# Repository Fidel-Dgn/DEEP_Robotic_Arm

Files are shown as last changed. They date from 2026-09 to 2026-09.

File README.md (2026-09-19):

# DEEP_Robotic_Arm
Ce dépôt contient le développement complet d’un bras robotique autonome basé sur un microcontrôleur STM32G431 et la DEEP Purple Complete Board. Le système est conçu pour détecter, saisir, trier et déplacer des objets grâce à une combinaison de capteurs, de servomoteurs et d’algorithmes embarqués.

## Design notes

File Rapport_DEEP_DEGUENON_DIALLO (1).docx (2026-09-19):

PROJET DEEP

Digital Embedded Electronics Project

Livraison finale

Bras robotique de tri automatique par couleur

Système mécatronique de détection et de tri RGB sur carte Nucleo STM32G431KB

Information | Détail
Nom du projet | Bras robotique de tri automatique par couleur
Étudiants | DEGUENON Fidel — DIALLO Seydou Idrissa
Encadrant | BOUVIER Thierry
Établissement | ESEO — Angers
Cible | Carte Nucleo STM32G431KB (DEEP Purple Complete Board)

# Sommaire

Sous Word : clic droit sur le sommaire → « Mettre à jour les champs » (ou sélectionnez tout puis F9) pour afficher les titres et les numéros de page avant l’export en PDF.

# Introduction

Ce projet a pour objectif la conception et la réalisation d’un système mécatronique autonome capable d’identifier la couleur d’un objet (rouge, vert ou bleu) et d’assurer son tri automatique. Le système repose sur un bras robotique articulé, actionné par cinq servomoteurs, qui manipule et déplace les objets vers des zones de tri dédiées.

L’identification de la couleur est effectuée à l’aide d’un capteur APDS-9960, tandis que l’ensemble du processus est piloté par un microcontrôleur STM32G431KB assurant la coordination entre la détection, la prise et le dépôt de l’objet. Une interface homme-machine, implémentée sur un écran TFT ILI9341, assure le suivi en temps réel du fonctionnement (état courant, distance de l’objet, composantes RGB mesurées et couleur détectée).

Ce rapport présente successivement le cahier des charges, le manuel d’utilisation, l’affectation des ports, l’architecture logicielle et la machine à états, les tests réalisés, le suivi du projet ainsi que l’analyse critique du travail. Les compléments retenus sont détaillés en annexe.

# 1. Compléments choisis

Afin de valoriser le travail réalisé et de couvrir les six points de compléments associés à la note de projet, l’équipe a retenu les compléments suivants. Le complément B (design de PCB) est obligatoire ; les autres ont été choisis pour leur pertinence vis-à-vis d’un système mécatronique embarqué.

Code | Complément retenu | Points
B | Routage de PCB avec Nucleo (carte d’interface / shield) | 3
E | Mesure de consommation et d’énergie selon scénarios | 2
G | Gestion de version du code source (Git) | 1
I | Impact environnemental (analyse du cycle de vie) | 3
T | Jeu de tests pour valider une fonctionnalité | 1
| Total de points ciblés (6 retenus sur la note) | 10

À adapter selon le travail réellement finalisé avant la remise : ne conservez que les compléments dont l’annexe correspondante est complétée. Les barèmes indiqués sont les valeurs maximales de la trame.

Brève introduction aux compléments. Le complément B décrit la conception d’une carte d’interface fiabilisant la connectique des servomoteurs et la séparation des alimentations. Le complément E analyse la consommation du système en régimes statique et dynamique. Le complément G assure la traçabilité du code via un dépôt Git distant. Le complément I propose un inventaire de cycle de vie et des pistes d’écoconception. Enfin, le complément T décrit un jeu de tests de validation des butées des servomoteurs.

# 2. Remise du matériel et réutilisation des composants

La récupération des matériels prêtés est essentielle au maintien de l’activité pratique et à la réutilisation des cibles fournies par STMicroelectronics. L’équipe coche ci-dessous la situation applicable.

Élément | État / Engagement
Numéro de la carte Nucleo | ______
Restitution des périphériques, de la carte Nucleo, du câble USB et de l’ensemble du matériel prêté | ☐ Déjà rendu
| ☐ Sera rendu sous 10 jours
| ☐ Remise lors d’une JPO / forum — Date : __/__/20__

Cochez la case applicable (sous Word : cliquez devant la case et tapez « x », ou utilisez la police Wingdings).

# 3. Cahier des charges

## 3.1 Contexte et expression du besoin

Dans un contexte industriel de logistique ou de contrôle qualité, le tri de petits composants selon un critère visuel simple (la couleur) est une opération répétitive qui se prête naturellement à l’automatisation. Le besoin exprimé est donc le suivant : disposer d’un démonstrateur autonome capable de détecter la couleur d’un objet présenté et de le déplacer vers la zone correspondante, sans intervention humaine.

- Objectif : automatiser le tri de petits objets en se basant sur leur couleur.
- Fonction principale : identifier puis déplacer les objets vers trois zones distinctes (Rouge, Vert, Bleu).

## 3.2 Description fonctionnelle (point de vue utilisateur)

Le système repose sur une architecture embarquée pilotée par la carte STM32G431KB. Le programme principal est structuré autour d’une machine à états finis qui gère séquentiellement les phases de fonctionnement. Les principaux éléments matériels sont :

- un capteur de couleur et de proximité APDS-9960 (bus I2C) ;
- un écran TFT ILI9341 (bus SPI) pour l’interface utilisateur ;
- un bras robotique articulé commandé par cinq servomoteurs (signaux PWM) ;
- le microcontrôleur STM32G431KB comme unité de traitement.

L’ensemble fonctionne en boucle infinie, assurant un traitement continu des données et des actions. Le cycle fonctionnel se résume ainsi :

Détection de présence → Analyse de la couleur → Décision → Mouvement du bras → Retour à l’attente

## 3.3 Limites et contraintes

Contraintes techniques. La carte Nucleo STM32G431KB impose des ressources limitées (broches, timers, mémoire). Les servomoteurs nécessitent une alimentation de puissance séparée afin d’éviter les perturbations électriques sur la partie logique. La gestion simultanée des périphériques (I2C, SPI, et cinq voies PWM réparties sur trois timers) constitue une contrainte forte de mise en œuvre et d’affectation des broches.

Limites fonctionnelles. Le tri est limité à trois couleurs (rouge, vert, bleu), avec une détection fondée sur une comparaison directe des composantes RGB. La précision du bras dépend des servomoteurs (commande en boucle ouverte) : l’absence de retour de position peut entraîner des imprécisions de placement.

# 4. Manuel d’utilisation

Ce manuel décrit la mise en œuvre du système du point de vue de l’utilisateur final. Aucune connaissance des outils de développement n’est nécessaire.

## 4.1 Alimentation

Le système requiert deux alimentations distinctes, à respecter impérativement :

- Alimentation de puissance : 5 V continu, capable de fournir de 1 A à 2,5 A, dédiée aux cinq servomoteurs du bras.
- Alimentation logique : 12 V continu en entrée, régulée en interne en 5 V (régulateur LM7805) puis en 3,3 V (régulateur LF33CV) pour la carte et les périphériques.

Les deux masses (GND puissance et GND logique) doivent être reliées. Ne pas alimenter les servomoteurs depuis le régulateur logique sous peine de chute de tension et de redémarrage du microcontrôleur.

## 4.2 Mise en route et utilisation

1. Mettre sous tension les deux alimentations ; la LED verte de la carte s’allume pour indiquer que le système est actif.
2. L’écran affiche le bandeau « ROBOTIC ARM PROJECT – ESEO » puis l’état courant en grand caractères. Le bras se place automatiquement en position de repos (état INIT).
3. Lorsque l’écran indique « ATTENTE OBJET », présenter un objet coloré sous le capteur. Une jauge de distance se remplit à l’approche de l’objet.
4. Une fois l’objet suffisamment proche, le système passe en « ANALYSE » : il affiche les valeurs Rouge, Vert et Bleu mesurées, ainsi qu’un carré de prévisualisation à la couleur détectée et le résultat (ROUGE, VERT ou BLEU).
5. Le bras saisit alors l’objet, pivote vers la zone correspondant à sa couleur, le dépose, puis revient en position d’attente pour l’objet suivant.

L’affichage permet à tout moment de savoir dans quel état se trouve la machine et quelle décision a été prise, sans recourir à un outil externe.

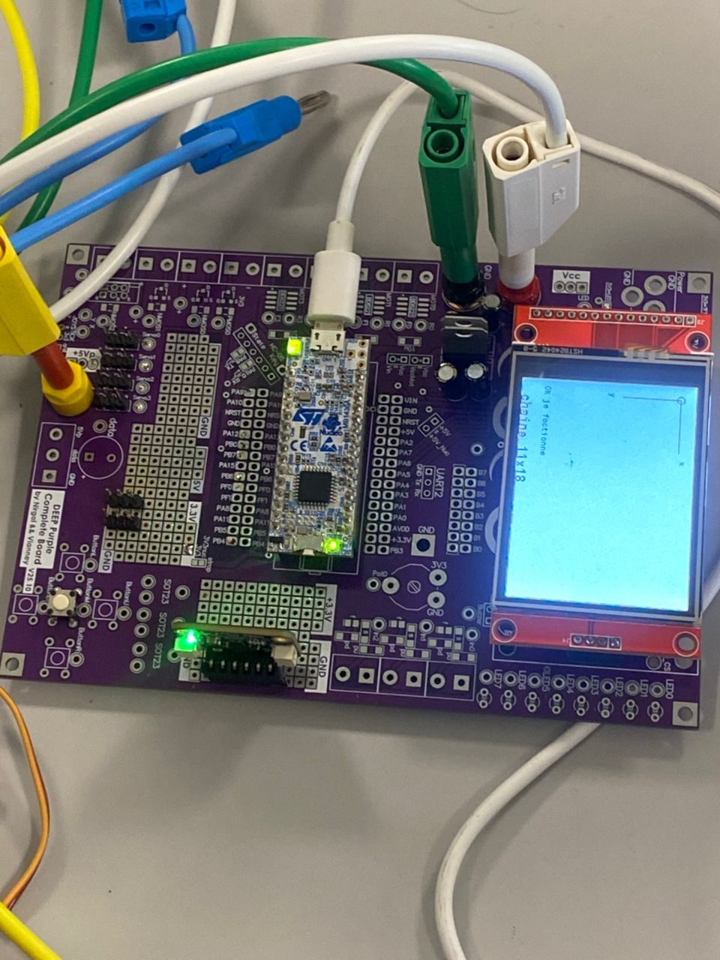
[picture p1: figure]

Figure 1 — Banc de test : carte DEEP Purple, Nucleo STM32G431KB et écran TFT ILI9341 actif.

# 5. Affectation des ports du microcontrôleur

Le tableau ci-dessous récapitule l’affectation des broches dans l’application. Les cinq voies de commande des servomoteurs (PWM) sont issues du code source (fichiers servo.c et main.c) et réparties sur trois timers.

Pin | Fonction dans le projet
PA9 | UART1 TX (réserve, non utilisé)
PA10 | PWM TIMER1_CH3 → Servo Coude
NRST | Reset microcontrôleur
GND | Masse
PA12 | SPI1 – contrôle écran TFT (CS / DC)
PB0 | PWM TIMER3_CH3 → Servo Épaule
PB7 | I2C1 SDA – capteur APDS-9960
PA15 | SPI1 / contrôle écran TFT
PB6 | I2C1 SCL – capteur APDS-9960
PF0 | Oscillateur (non utilisé)
PF1 | Oscillateur (non utilisé)
PA8 | Libre
PA11 | USB (non utilisé)
PB5 | Libre
PB4 | PWM TIMER3_CH1 → Servo Base
VIN | Alimentation carte (5 V)
GND | Masse
NRST | Reset
5V | Alimentation périphériques
PA2 | UART2 TX → PC (printf, 115200 bauds)
PA7 | SPI1 MOSI – écran TFT
PA6 | SPI1 MISO – écran TFT
PA5 | SPI1 SCK – écran TFT
PA4 | SPI1 CS – écran TFT
PA3 | UART2 RX ← PC
PA1 | PWM TIMER2_CH2 → Servo Pince
PA0 | PWM TIMER2_CH1 → Servo Poignet
AVDD | Alimentation analogique
3V3 | Alimentation logique
PB3 | SPI1 / contrôle écran TFT
PB8 | LED verte (indication système actif)

Aucun GPIO Expander n’a été utilisé : les 5 voies PWM, le bus SPI, le bus I2C et l’UART tiennent directement sur les broches de la Nucleo G431KB.

# 6. Câblage du PCB

Les périphériques sont intégrés sur la DEEP Purple Complete Board, qui accueille la carte Nucleo et les barrettes de connexion soudées pour les servomoteurs, le capteur et l’écran. La photographie ci-dessous présente une vue d’ensemble de la maquette ; le routage du PCB d’interface dédié est détaillé en Annexe B.

Figure 2 — Vue d’ensemble de la maquette câblée (recto).

[À INSÉRER : photo recto-verso du PCB d’interface câblé / soudé, une fois disponible]

# 7. Description d’un algorithme du programme

Le comportement global du système est décrit par une machine à états finis (FSM) implémentée dans la boucle principale du fichier main.c. Quatre états structurent le fonctionnement : INIT, WAIT_APDS, DECISION et TRIE. Le diagramme suivant présente les états et les conditions de transition.

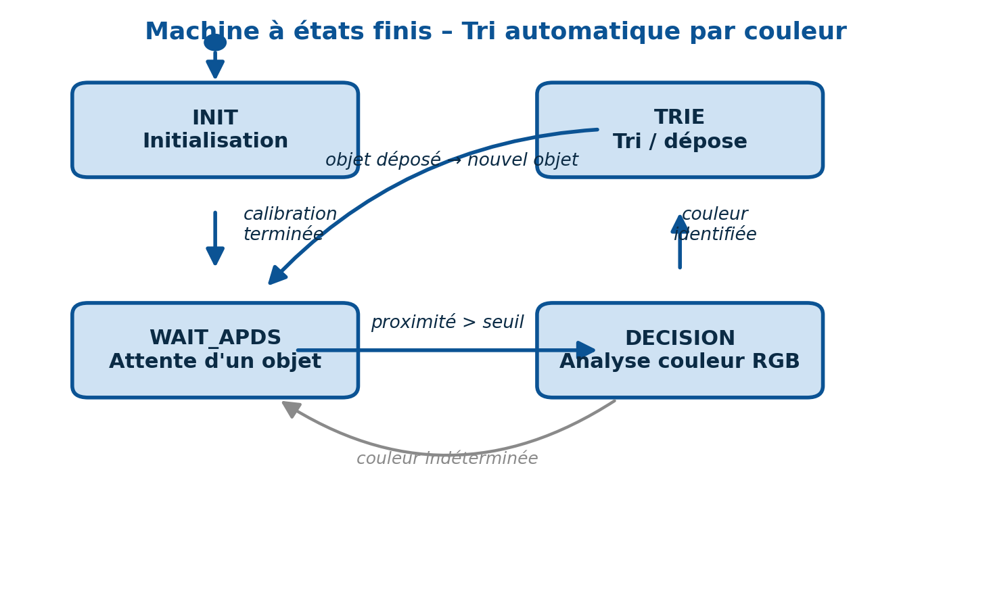
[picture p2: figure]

Figure 3 — Machine à états finis du système de tri.

## 7.1 Description des états

- INIT (Initialisation) — le système initialise et calibre le capteur APDS-9960, place le bras en position de repos (SERVO_set_position_INIT) puis active le capteur. La transition vers WAIT_APDS est inconditionnelle après une temporisation.
- WAIT_APDS (Attente d’un objet) — lecture continue de la proximité ; une jauge est affichée à l’écran. Lorsque la valeur dépasse le seuil PROXIMITY_THRESHOL, le système passe en DECISION.
- DECISION (Analyse) — lecture des composantes Rouge, Vert et Bleu. La couleur dominante est déterminée par comparaison directe ; la position de base cible est mémorisée (target_base_angle) et le système passe en TRIE. Si aucune couleur ne domine, retour à WAIT_APDS.
- TRIE (Tri / dépose) — le bras saisit l’objet (SERVO_pick_object), pivote vers la zone correspondante et dépose l’objet (SERVO_drop_at), puis revient en position initiale avant de repasser en WAIT_APDS.

## 7.2 Table de transition

État courant | Condition de transition | État suivant
INIT | Calibration terminée (temporisation) | WAIT_APDS
WAIT_APDS | proximité > PROXIMITY_THRESHOL | DECISION
DECISION | Couleur dominante identifiée (R, G ou B) | TRIE
DECISION | Couleur indéterminée | WAIT_APDS
TRIE | Objet déposé et bras revenu au repos | WAIT_APDS

## 7.3 Pseudo-code de la boucle principale

tant que (vrai) :
si (etat != etat_precedent) : rafraichir l'ecran (bandeau + nom d'etat)
selon etat :
INIT : init capteur ; bras au repos ; etat <- WAIT_APDS
WAIT_APDS : lire proximite ; afficher jauge
si proximite > SEUIL : etat <- DECISION
DECISION : lire R, G, B ; afficher valeurs
si R max : cible <- ROUGE ; etat <- TRIE
sinon si G max : cible <- VERT ; etat <- TRIE
sinon si B max : cible <- BLEU ; etat <- TRIE
sinon : etat <- WAIT_APDS
TRIE : SERVO_pick_object() ; SERVO_drop_at(cible)
SERVO_set_position_INIT() ; etat <- WAIT_APDS

# 8. Structure du programme

Le projet s’appuie sur le squelette BSP fourni pour la carte Nucleo STM32G431KB. Le code spécifiquement développé par l’équipe se trouve dans le dossier app/. Les modules matériels (écran, capteur, timers, bus de communication) sont pilotés via les drivers BSP réutilisés. Les fichiers produits par l’équipe sont décrits ci-dessous.

## 8.1 Fichier « config.h »

Fichier central de configuration : il active les modules logiciels utilisés par le projet. Sont activés ici l’écran ILI9341 (USE_ILI9341), le capteur APDS-9960 (USE_APDS9960), les timers (USE_BSP_TIMER) ainsi que les bus I2C et SPI (activés automatiquement par dépendance). Les UART1 et UART2 sont configurés respectivement sur PA9/PA10 et PA2/PA3, et la LED verte sur PB8.

## 8.2 Fichier « main.c »

Point d’entrée de l’application. Il réalise l’initialisation matérielle (HAL, écran, GPIO, UART à 115200 bauds, capteur, servomoteurs) puis exécute la machine à états dans la boucle infinie. Il gère également l’affichage de l’interface (bandeau, état courant, jauge de proximité, valeurs RGB et résultat de tri).

Fonction | Développeur | Description
main | F. Deguenon | Initialisation des périphériques et exécution de la machine à états (INIT, WAIT_APDS, DECISION, TRIE).
isButtonPressed | F. Deguenon | Teste si les coordonnées tactiles tombent dans la zone d’un bouton de l’écran.
write_LED | S. Diallo | Pilote l’état de la LED verte (témoin système).
char_received | S. Diallo | Indique si un caractère a été reçu sur l’UART et vide le buffer.
heartbeat | S. Diallo | Fait clignoter la LED tant qu’aucun caractère n’est reçu (témoin de vie).
TestCharReceiveUart | F. Deguenon | Émet bit à bit un caractère sur PA5 pour visualisation à l’oscilloscope (debug).
Test_Ecran | S. Diallo | Séquence de test de l’écran (couleurs, formes, texte).
example_rgb_read | F. Deguenon | Lecture et affichage des composantes ambiante/RGB via printf (debug).

## 8.3 Fichiers « servo.c » / « servo.h »

Module de pilotage des cinq servomoteurs du bras. Chaque servo est commandé par un signal PWM de période 20 ms (50 Hz) généré par les timers TIMER1, TIMER2 et TIMER3. La position est exprimée via le rapport cyclique réglé par BSP_TIMER_set_duty. Le module fournit les séquences de mouvement de préhension et de dépose.

Fonction | Développeur | Description
SERVO_init | Équipe | Lance les 3 timers à 20 ms et active les 5 voies PWM (Base PB4, Épaule PB0, Coude PA10, Poignet PA0, Pince PA1).
SERVO_set_position_INIT | Équipe | Place le bras en position de repos (valeurs de duty de référence).
SERVO_pick_object | F. Deguenon | Séquence de préhension : ouverture pince, descente, fermeture sur l’objet, remontée.
SERVO_drop_at | F. Deguenon | Pivote la base vers la zone de la couleur, ouvre la pince pour déposer puis relève le bras.
SERVO_process_test | S. Diallo | Routine de test d’un servo (balayage de positions, incrément sur bouton).
SERVO_set_position / SERVO_get_position | Équipe | Conversion position (0–100 %) → rapport cyclique (version de référence, conservée en commentaire).

## 8.4 Drivers BSP réutilisés

Outre le code applicatif, le projet s’appuie sur les drivers BSP fournis : stm32g4_ili9341 (écran TFT, SPI), APDS9960/stm32g4_apds9960 (capteur couleur/proximité, I2C), stm32g4_timer (génération PWM), stm32g4_i2c et stm32g4_spi (bus), stm32g4_uart (liaison série), stm32g4_gpio et stm32g4_systick (GPIO et base de temps).

# 9. Tests

Cette section présente les tests réalisés à chaque étape de la mise au point, avec le mode opératoire et le résultat observé. Ce rapport de test permet de situer l’état d’avancement de la réalisation.

Intitulé du test | Mode opératoire / observation attendue | Observation et conclusion
Alimentation 5 V de puissance | Mesure de la ligne 5 V dédiée aux servomoteurs ; doit rester stable en charge. | OK – tension stable mesurée à l’oscilloscope (voir Fig. 4).
Sortie régulateur LM7805 (5 V) | Mesure au voltmètre / oscilloscope de la sortie du LM7805. | OK – 4,96 V mesurés (voir Fig. 5).
Sortie régulateur LF33CV (3,3 V) | Mesure de la sortie 3,3 V alimentant la logique. | OK – 3,28 V mesurés (voir Fig. 6).
Liaison UART Tx → PC | Envoi de caractères depuis la STM32 (« Hi ») visualisés à l’oscilloscope et sur le terminal Docklite. | OK – trame série correcte observée (voir Fig. 7).
Écran TFT ILI9341 | Initialisation et affichage d’une chaîne de caractères. | OK – affichage correct (voir Fig. 1).
Servomoteurs (PWM) | Visualisation des impulsions PWM (20 ms) générées par les timers à l’oscilloscope. | OK – largeurs d’impulsion variables selon la commande (voir Fig. 8).
Bus I2C – APDS-9960 | Observation des lignes SDA et SCL lors des échanges avec le capteur. | OK – trames I2C présentes (voir Fig. 9 et 10).
Détection de couleur RGB | Présenter un objet rouge/vert/bleu et vérifier le résultat affiché. | Partiel – détection fonctionnelle mais sensible à l’éclairage ambiant et au gain du capteur.
Séquence complète de tri | Cycle détection → préhension → dépose → retour. | En cours – cinématique du bras en finalisation.

## 9.1 Mesures d’alimentation

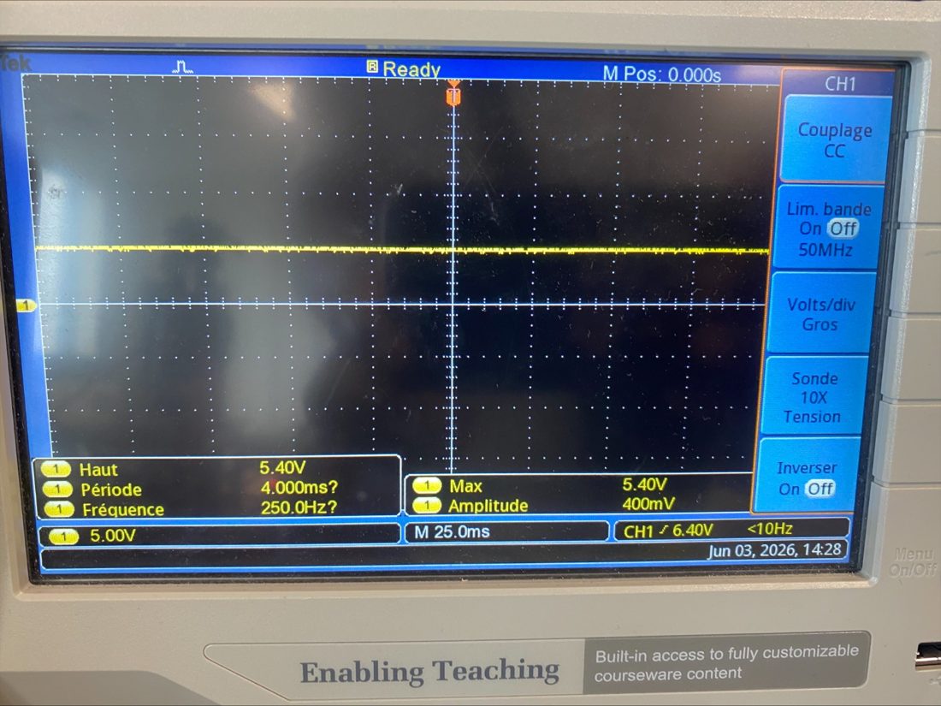
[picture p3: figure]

Figure 4 — Ligne d’alimentation 5 V de puissance (servomoteurs).

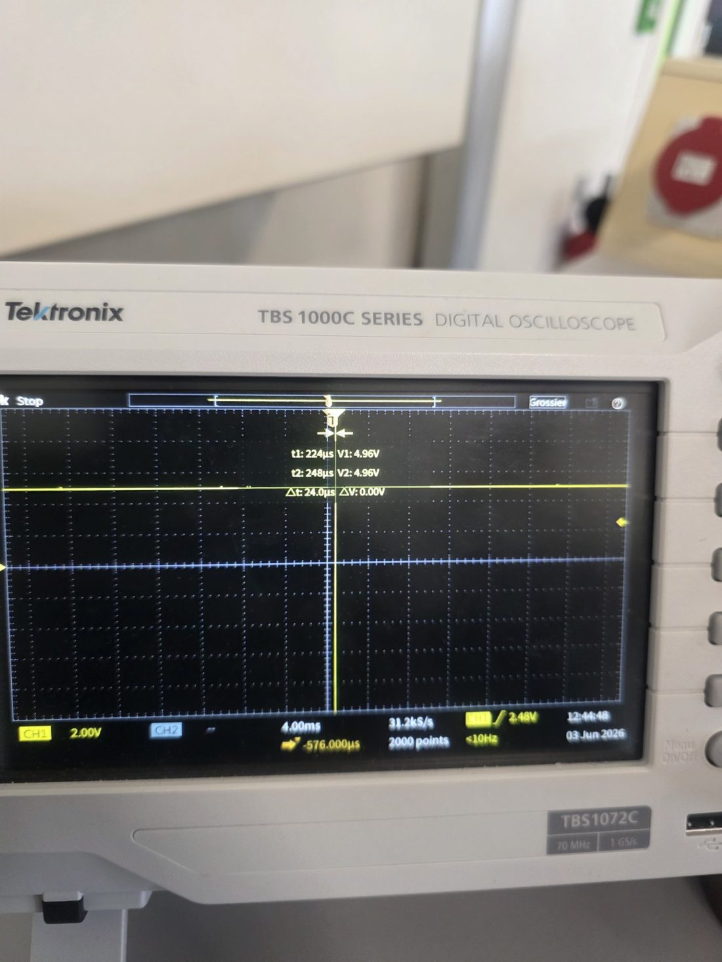
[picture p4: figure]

Figure 5 — Sortie du régulateur LM7805 : 4,96 V.

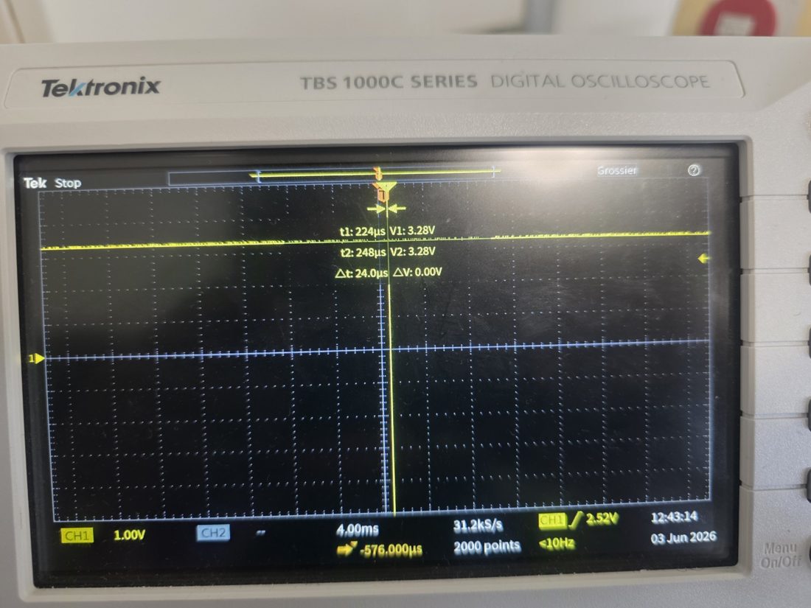
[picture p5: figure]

Figure 6 — Sortie du régulateur LF33CV : 3,28 V.

## 9.2 Communications et actionneurs

Le test de l’UART vérifie l’intégrité de la liaison bidirectionnelle entre la STM32 et le PC. La configuration utilise l’UART2 (PA2). Les premiers caractères émis (« Hi ») ont été visualisés à l’oscilloscope.

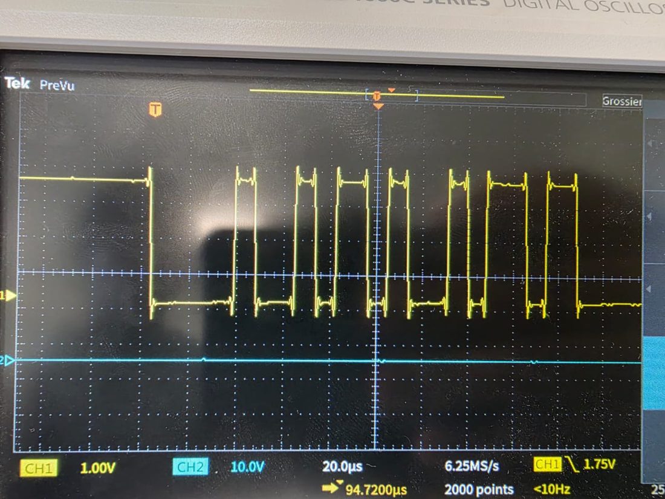
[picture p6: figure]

Figure 7 — Trame série UART (émission des caractères « Hi »).

Le test des servomoteurs valide la génération des impulsions PWM par les timers. Les largeurs d’impulsion varient correctement selon la commande, confirmant la capacité du microcontrôleur à piloter les servos.

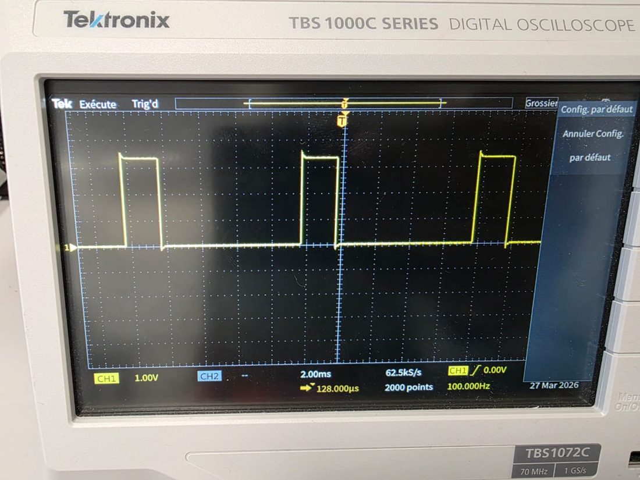
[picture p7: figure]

Figure 8 — Signaux PWM de commande des servomoteurs (période 20 ms).

Le test du capteur APDS-9960 vérifie la communication sur le bus I2C1 : ligne de données SDA et ligne d’horloge SCL. Les trames I2C sont bien présentes lors des échanges, validant l’initialisation du bus et le dialogue avec le capteur.

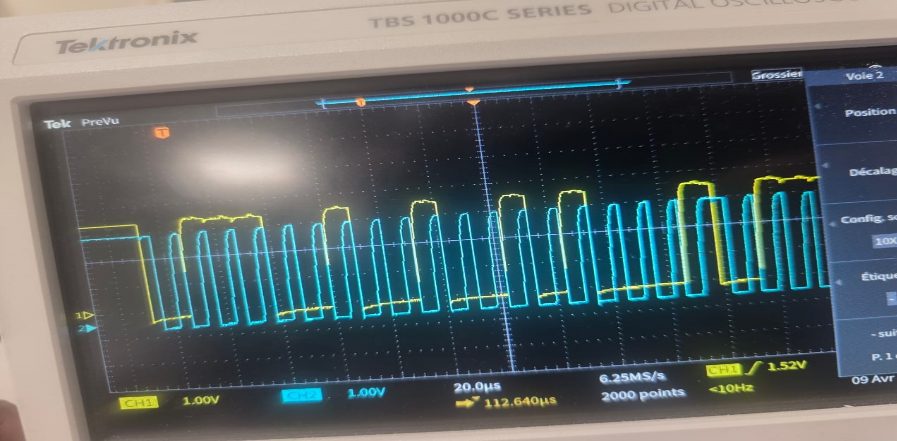
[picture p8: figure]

Figure 9 — Échanges I2C (SDA en jaune, SCL en bleu).

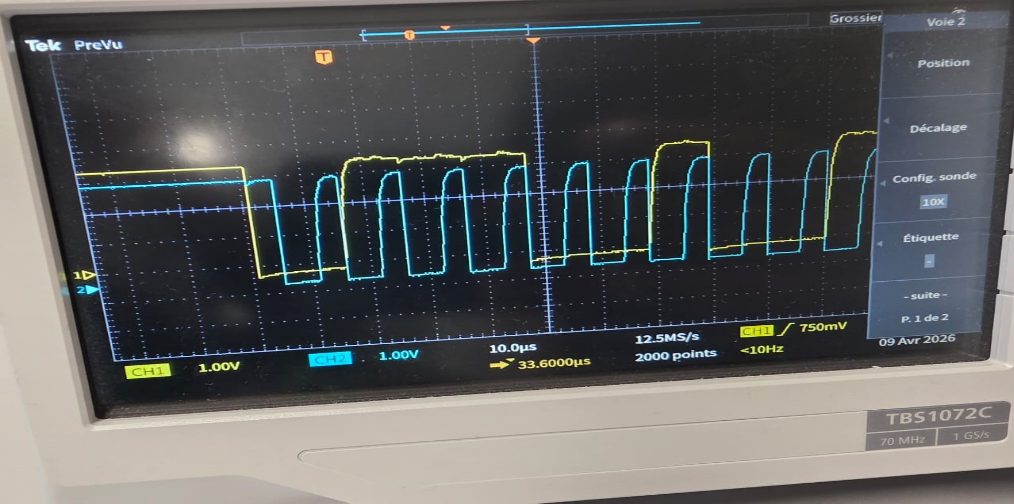
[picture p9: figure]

Figure 10 — Détail des trames I2C (données et horloge).

# 10. Cahier de suivi

Ce cahier retrace l’évolution du projet séance par séance : tâches réalisées, réalisateurs, difficultés rencontrées et actions à mener ensuite.

Date | Tâches, réalisateurs, difficultés rencontrées | À faire la prochaine fois
06/03 | Choix du sujet et définition du projet de bras robotique de tri. Répartition des tâches (F. Deguenon / S. Diallo). | Conception du système et architecture globale.
11/03 | Soudure des composants et barrettes sur la DEEP Purple Complete Board. Difficulté : organisation du câblage. (F. / S.) | Finalisation de l’intégration des périphériques.
13/03 | Gestion de l’alimentation : séparation puissance / logique pour éviter les parasites. Difficulté : stabilité électrique. | Tests UART et servomoteurs.
18/03 | Tests de communication UART entre la carte et le terminal PC. (F. Deguenon) | Intégration de l’écran TFT.
25/03 | Tests de l’écran ILI9341 et affichage des données. Début des tests PWM. Difficulté : réglage des fréquences PWM (tremblements). | Intégration des servomoteurs au bras.
27/03 | Tests des servomoteurs (timers PWM) et mouvements de base. Difficulté : calibration des angles et synchronisation. | Implémentation du capteur APDS-9960 en I2C.
01/04 | Implémentation et tests du bus I2C pour l’APDS-9960. Difficulté : instabilité I2C et erreurs de communication. | Stabilisation I2C et amélioration de la détection.
08/04 | Mise en place de la machine à états (INIT, WAIT_APDS, DECISION, TRIE). (F. Deguenon) | Finalisation de la logique de tri et intégration.
10/04 | Conception du PCB et organisation des signaux. Difficulté : conflits de GPIO entre modules. | Finalisation du routage PCB.
22/04 | Mise en ligne du projet sur Git (gestion de version et sauvegarde). (F. / S.) | Tests globaux et optimisation.
29/04 | Tests globaux et intégration complète. Début de la cinématique du bras. Difficultés : cinématique complexe, conflits GPIO. | Finalisation de la cinématique et optimisation.

# 11. État d’avancement et analyse du projet

## 11.1 État d’avancement

Le projet est bien avancé sur la partie matérielle et partiellement fonctionnel sur la partie logicielle.

Réalisations matérielles :

- intégration de la DEEP Purple Complete Board et des périphériques ;
- soudure des composants et mise en place des barrettes de connexion ;
- gestion de l’alimentation et vérification de la stabilité des tensions ;
- organisation du câblage entre les modules.

Réalisations logicielles :

- communication UART carte ↔ PC opérationnelle ;
- affichage TFT fonctionnel (interface et debug) ;
- commande des servomoteurs par PWM validée ;
- communication I2C avec le capteur APDS-9960 établie ;
- machine à états implémentée et enchaînement des états validé.

Points restant à finaliser :

- fiabilisation de la détection de couleur (gain capteur, conditions d’éclairage) ;
- calibration fine de la cinématique du bras (angles de préhension et de dépose) ;
- validation du cycle de tri complet en conditions réelles.

## 11.2 Analyse du travail réalisé

Analyse du matériel. Si la partie matérielle devait être refaite, plusieurs améliorations seraient envisagées : meilleure planification du câblage dès le départ, connecteurs plus robustes et standardisés pour éviter les faux contacts, ajout d’une plaque de distribution d’alimentation, et séparation plus nette des circuits de puissance et de logique pour réduire les perturbations.

Analyse du logiciel. Le code fonctionne pour les fonctions de base mais gagnerait à être davantage modularisé (séparation nette moteurs / communication / capteurs) et à remplacer les temporisations bloquantes (HAL_Delay) par une gestion non bloquante afin de fluidifier l’IHM pendant les mouvements.

Débogage. L’oscilloscope s’est révélé l’outil le plus utile (UART, PWM, I2C). Avec le recul, l’analyseur logique aurait pu être employé plus tôt pour déchiffrer les trames I2C et accélérer la stabilisation du capteur.

Difficultés principales. Instabilité de l’alimentation lors de l’activation simultanée de plusieurs servomoteurs ; conflits d’affectation de GPIO entre PWM, SPI et I2C ; complexité du câblage rendant certains diagnostics longs ; nombreux essais itératifs pour stabiliser les communications.

# 12. Conclusion

Ce projet de bras robotique illustre une démarche complète d’ingénierie, de la conception matérielle à l’implémentation logicielle jusqu’à la validation expérimentale. L’architecture fondée sur une machine à états finis a permis un fonctionnement structuré et lisible du système, et chaque brique (alimentation, UART, écran, PWM, I2C) a été validée individuellement à l’oscilloscope.

Au-delà des résultats, le projet met en évidence les défis concrets des systèmes embarqués : gestion de l’énergie, séparation des alimentations, affectation des broches sous contrainte, précision des actionneurs en boucle ouverte. La principale difficulté surmontée a été la stabilisation conjointe des alimentations et des bus de communication face à la charge variable des servomoteurs.

Le système constitue une base solide pour des développements futurs : fiabilisation de la détection de couleur, passage à une commande non bloquante et calibration fine de la cinématique. Il reflète une approche rigoureuse de la conception d’un système robotique complet.

# Annexe B — Design de PCB (complément obligatoire)

Cette annexe présente la carte d’interface conçue pour fiabiliser la connectique des servomoteurs, des bus et de l’alimentation autour de la Nucleo STM32G431KB.

## B.1 Auto-validation avant fabrication

Critère de validation | Statut
Fichiers SchDoc, PcbDoc et PDF (schéma + couches + vue 3D) joints à l’archive zip | ☐
Chaque point de la « fiche validation PCB avant fabrication » consulté | ☐
Connecteurs accessibles | ☐
Plan de masse présent sur chaque couche de cuivre | ☐
Tous les GND reliés par des pistes | ☐
DRC (Design Rules Check) sans aucune erreur | ☐
Connecteur UART présent (Rx + Tx + GND) | ☐
Connecteur de programmation si microcontrôleur en CMS (SWDIO + SWDCLK + GND) | ☐
Noms des étudiants et site (Angers) visibles sur le TOP | ☐
Dimensions raisonnables, pistes ≥ 10 mils (20 si possible), clearance ≥ 20 mils si possible | ☐

## B.2 Auto-évaluation

Critère | Note / 100
Qualité du schéma | ____ / 100
Qualité du placement | ____ / 100
Qualité du routage | ____ / 100

## B.3 Schéma, routage et vue 3D

[À INSÉRER : extraits du schéma (capture) avec explication du rôle des composants/périphériques]

[À INSÉRER : vue 2D du routage, plans de masse masqués]

[À INSÉRER : vue 3D du PCB (Top, et Bottom si pertinent)]

Difficultés rencontrées : conflits d’affectation de GPIO entre PWM, SPI et I2C lors du placement, et acheminement des pistes d’alimentation de puissance séparées de la partie logique.

## B.4 Estimation du coût de production

[À INSÉRER : capture de l’estimation de coût (JLCPCB, Eurocircuits, …) à partir des fichiers Gerber]

# Annexe E — Mesure de consommation et d’énergie selon scénarios

L’alimentation est un enjeu critique du système, notamment du fait des cinq servomoteurs dont la consommation varie fortement selon qu’ils sont au repos ou en mouvement.

## E.1 Modes de fonctionnement

- Mode veille / attente : capteur actif, écran statique, servomoteurs maintenus en position (couple de maintien).
- Mode actif : analyse couleur et mouvement simultané de plusieurs servomoteurs (pic de courant).

## E.2 Mesures par mode

Mode / scénario | Courant mesuré | Observations
Repos (attente d’objet) | ____ mA | À compléter
Analyse (capteur + écran) | ____ mA | À compléter
Mouvement (préhension) | ____ mA (pic) | À compléter
Cycle de tri complet | ____ mAh | À compléter

Relevés à compléter avec la méthodologie de la notice « Complément E ». Penser à décrire un scénario type et à estimer l’énergie consommée (voire le dimensionnement d’une batterie).

## E.3 Pistes de réduction de la consommation

- Couper l’alimentation des servomoteurs hors mouvement (relais / MOSFET de puissance).
- Mettre le microcontrôleur en mode veille (Sleep/Stop) pendant l’attente, réveil sur interruption de proximité.
- Réduire la fréquence de rafraîchissement de l’écran et désactiver le capteur entre deux objets.

# Annexe G — Gestion de version du code source (Git)

Le code source du projet est géré sous Git et hébergé sur un dépôt distant, assurant la traçabilité des modifications et facilitant le travail collaboratif entre les deux membres de l’équipe.

Dépôt : https://github.com/Fidel-Dgn/stm32-projet-robotic-arm.git

[À INSÉRER : capture d’écran de l’historique des révisions (dates et auteurs des commits visibles)]

## Retour d’expérience

L’utilisation de Git a permis de sauvegarder régulièrement le travail et de revenir à une version stable après une modification problématique (notamment lors de la mise au point de l’I2C et des réglages PWM). Le suivi des commits étalés sur la durée du projet reflète la progression réelle du développement, depuis l’intégration des périphériques jusqu’à la machine à états.

# Annexe I — Impact environnemental

En s’appuyant sur le cours du semestre 5, cette annexe esquisse l’inventaire du cycle de vie (ICV) d’un équivalent industriel du bras robotique de tri, puis propose des pistes d’écoconception. Le périmètre retenu est volontairement simplifié pour cette étude.

## I.1 Inventaire du cycle de vie (ICV) — périmètre simplifié

Phase | Principaux flux / impacts
Extraction & matériaux | Cuivre (PCB, câblage), plastiques (servos, boîtier), silicium (microcontrôleur, capteur), métaux des connecteurs.
Fabrication | Gravure et métallisation du PCB (consommables chimiques, eau), assemblage et soudure (énergie, alliages).
Distribution | Transport des composants (souvent importés) et du produit fini.
Utilisation | Consommation électrique (servos, logique) sur la durée de vie ; source d’énergie déterminante.
Fin de vie | DEEE : tri, recyclage des métaux et du PCB, traitement des plastiques.

## I.2 Trois pistes d’écoconception

6. Sobriété énergétique : mise en veille du microcontrôleur et coupure des servomoteurs hors mouvement (cf. Annexe E) pour réduire l’impact de la phase d’utilisation, généralement dominante.
7. Durabilité et réparabilité : connecteurs standardisés et modules enfichables (capteur, écran, bras) pour faciliter le remplacement d’un seul composant défaillant plutôt que de l’ensemble.
8. Conception matière : PCB de dimensions optimisées (moins de cuivre et de substrat), boîtier en matériau recyclé/recyclable et limitation du nombre de références de composants.

# Annexe T — Jeu de tests de validation

Le projet dispose d’une fonctionnalité se prêtant à un jeu de tests : la validation des butées et des positions de référence des servomoteurs à la mise sous tension, afin de garantir que le bras ne force pas mécaniquement et atteint bien ses positions clés.

## T.1 Cas de test

N° | Cas testé / action | Résultat attendu
1 | Mise sous tension : appel de SERVO_set_position_INIT. | Chaque servo rejoint sa position de repos sans forcer.
2 | Commande de la base aux positions ROUGE / VERT / BLEU. | La base s’oriente vers les trois angles distincts attendus.
3 | Commande pince ouverte puis fermée. | La pince atteint les deux butées sans blocage.
4 | Position de duty hors plage (< min ou > max). | La valeur est écrêtée ; aucun mouvement dangereux.
5 | Séquence SERVO_pick_object puis SERVO_drop_at. | Préhension et dépose enchaînées, retour au repos.

La pertinence de ce jeu de tests réside dans la couverture des positions extrêmes (butées) et des transitions critiques, qui sont les situations les plus susceptibles d’endommager les servomoteurs ou la mécanique du bras.

DEGUENON Fidel – DIALLO Seydou Idrissa | Page

Projet DEEP — Bras robotique de tri par couleur

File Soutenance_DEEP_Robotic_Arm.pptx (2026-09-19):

## Projet d’électronique numérique

Bras robotique de tri automatique par couleur
Système mécatronique de détection et de tri RGB sur carte Nucleo STM32G431KB
Encadré par BOUVIER Thierry — ESEO Angers 2025

Projet réalisé par :
DEGUENON Fidel
DIALLO Seydou Idrissa

2023

ESEO :: Présentation du projet d’électronique numérique :: 2025

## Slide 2

Quelques conseils pour rédiger un support de présentation…
Sur chaque slide, posez vous les questions suivantes :
« quel message je veux faire passer » ?
Puis-je expliquer ce message avec une image :
Chronogramme, graphique, dessin, schéma, croquis, illustration, photo, …
Y-a-t-il beaucoup de texte ? / Puis-je résumer en quelques items ?
Est-ce lisible de loin / suffisamment contrasté ?
Est-ce que cette slide va servir mon discours ?

## Sommaire

- But du projet
- Fonctionnalités du dispositif
- Capteurs et actionneurs utilisés
- Développement matériel
  - Architecture
  - Problèmes rencontrés
- Développement logiciel
  - Architecture
  - Etats du système
  - Tests
  - Problèmes rencontrés
- Perspectives d’évolutions

## But du projet

- Contexte industriel :
  - Dans la logistique et le contrôle qualité, le tri visuel de composants est une tâche répétitive idéale pour l’automatisation.
- Objectif du projet :
  - Concevoir un système mécatronique autonome capable de détecter la couleur d’un objet (rouge, vert, bleu) et de le trier automatiquement.
- Fonction principale :
  - Identifier puis déplacer les objets vers 3 zones distinctes (Rouge, Vert, Bleu) sans intervention humaine.

## Spécifications

- Fonctionnalités principales
  - Détection de couleur (rouge, vert, bleu) via capteur APDS-9960
  - Tri automatique vers 3 zones dédiées — sans intervention humaine
  - Bras articulé 5 servomoteurs : base, épaule, coude, poignet, pince
  - Interface HMI sur écran TFT ILI9341 (état, distance, RGB, couleur détectée)
- Limites et contraintes
  - Tri limité à 3 couleurs — détection par comparaison directe des composantes RGB
  - Commande en boucle ouverte : précision dépendante des servomoteurs

## Composants utilisés

- Capteur APDS-9960 (I2C)
  - Détection de proximité et mesure des composantes Rouge, Vert, Bleu
- Microcontrôleur STM32G431KB (carte Nucleo)
  - Unité de traitement centrale — gestion I2C, SPI, PWM, UART
- 5 Servomoteurs (PWM 50 Hz)
  - Base (PB4), Épaule (PB0), Coude (PA10), Poignet (PA0), Pince (PA1)
- Écran TFT ILI9341 (SPI)
  - Affichage temps réel de l’état, proximité, valeurs RGB et résultat de tri
- Alimentation double
  - 5V puissance (servos) + 12V régulé en 5V (LM7805) puis 3,3V (LF33CV) pour logique

## Capteur de température DS18B20

- Principe de fonctionnement
  - Le capteur APDS-9960 mesure l’intensité lumineuse réfléchie dans les canaux Rouge, Vert, Bleu et Clear via des photodiodes internes.
- Protocole de communication : I2C (bus I2C1)
  - SDA → PB7 — SCL → PB6
  - Adresse I2C : 0x39 — driver BSP : stm32g4_apds9960
- Point technique : correction de saturation
  - Gain fixé à AGAIN_1X pour éviter la saturation des valeurs RGB en éclairage fort
- Limite
  - Détection sensible à l’éclairage ambiant — comparaison RGB directe sans correction colorimétrique

## Actionneur

- Principe de pilotage des servomoteurs
  - Signal PWM période 20 ms (50 Hz) — position codée par la largeur d’impulsion (1–2 ms)
  - Rapport cyclique réglé par BSP_TIMER_set_duty() via TIMER1, TIMER2, TIMER3
- Répartition des voies PWM
  - TIM3_CH1 (PB4) → Base — TIM3_CH3 (PB0) → Épaule
  - TIM1_CH3 (PA10) → Coude — TIM2_CH1 (PA0) → Poignet — TIM2_CH2 (PA1) → Pince
- Séquences de mouvement
  - SERVO_pick_object() : ouverture pince, descente, saisie, remontée
  - SERVO_drop_at() : pivot vers la zone couleur, dépose, retour repos

## Développement matériel

- DEEP Purple Complete Board
  - Carte d’interface accueillant la Nucleo + barrettes servos + connecteurs capteur/écran
- PCB conçu sous Altium Designer
  - Plan de masse sur chaque couche, DRC sans erreur, Gerber générés pour JLCPCB (5 exemplaires)
- Problèmes rencontrés
  - Conflits de GPIO entre PWM, SPI et I2C — résolu par affectation rigoureuse des broches
  - Instabilité de l’alimentation lors de l’activation simultanée de plusieurs servos — séparation puissance/logique
- Auto-évaluation PCB
  - Schéma 90/100 — Placement 95/100 — Routage 98/100

## Développement logiciel

- Découpage en modules
  - config.h — activation des modules (ILI9341, APDS9960, timers, I2C, SPI, UART)
  - main.c — init matérielle + machine à états + interface TFT
  - servo.c / servo.h — pilotage PWM des 5 servomoteurs + séquences pick/drop
  - Drivers BSP réutilisés : stm32g4_ili9341, stm32g4_apds9960, stm32g4_timer, stm32g4_i2c, stm32g4_spi, stm32g4_uart
- Rôle de chaque module
  - main.c : chef d’orchestre — servo.c : actionneur — APDS driver : détection — ILI9341 driver : affichage

## Développement logiciel - Etats du système

- Machine à 4 états (FSM)
  - INIT → calibration APDS-9960, position de repos → transition inconditionnelle vers WAIT_APDS
  - WAIT_APDS → lecture proximité en continu + jauge écran → si proximité > seuil : DECISION
  - DECISION → lecture RGB, couleur dominante → si identifiée : TRIE — sinon : retour WAIT_APDS
  - TRIE → SERVO_pick_object + pivot base + SERVO_drop_at + retour repos → WAIT_APDS
- Cycle fonctionnel complet
  - Détection de présence → Analyse couleur → Décision → Mouvement bras → Retour attente

## Développement logiciel - tests

- Approche itérative : validation périphérique par périphérique
  - Alimentation 5V puissance : OK — LM7805 : 4,96V — LF33CV : 3,28V
  - UART2 (PA2) : trame série correcte observée à l’oscilloscope (Docklite)
  - Servomoteurs PWM : largeurs d’impulsion variables selon commande — OK
  - Bus I2C APDS-9960 : trames SDA/SCL présentes — OK
  - Détection RGB : fonctionnelle — sensible à l’éclairage ambiant
  - Cycle complet de tri : implémenté, testé et validé (séance 05/06)

## Développement logiciel – problèmes rencontrés

- Problèmes rencontrés
  - Instabilité I2C lors des premiers tests — résolu par stabilisation du bus et du timing
  - Tremblements des servos au départ — réglage des fréquences PWM et calibration des angles
  - HAL_Delay() bloquant dans l’état DECISION — gel de l’IHM pendant les mouvements
  - Conflits GPIO entre PWM, SPI et I2C — résolution par affectation rigoureuse (voir tableau broches)
  - Cinématique complexe du bras — nombreux essais itératifs pour calibrer les positions

## Démonstration

- Démonstration live du système
  - 1. Mise sous tension : LED verte allumée, écran affiche « ROBOTIC ARM PROJECT – ESEO »
  - 2. État ATTENTE OBJET : jauge de proximité se remplit à l’approche
  - 3. État ANALYSE : affichage RGB + carré de prévisualisation couleur + résultat ROUGE/VERT/BLEU
  - 4. TRI : bras saisit l’objet, pivote, dépose dans la zone, revient en attente

## Perspectives

- Améliorations logicielles
  - Remplacer les HAL_Delay() bloquants par une gestion non bloquante (Systick/interruptions)
  - Meilleure modularisation du code : séparation nette moteurs / communication / capteurs
- Améliorations matérielles
  - Fiabilisation de la détection de couleur (correction colorimétrique, compensation luminosité)
  - Calibration fine de la cinématique — ajout d’un retour de position (encodeurs)
- Extension fonctionnelle
  - Tri de plus de 3 couleurs — vision artificielle (caméra) — boîtier CAO dédié

## Conclusion

- Un projet d’ingénierie complet
  - De la conception matérielle (PCB, câblage, alimentation) à l’implémentation logicielle (FSM, PWM, I2C, SPI) jusqu’à la validation expérimentale.
- Points clés retenus
  - Architecture FSM lisible — chaque brique validée individuellement à l’oscilloscope
  - Cycle de tri complet fonctionnel : détection → préhension → dépose
- Défis surmountés
  - Stabilisation des alimentations et des bus face à la charge variable des servomoteurs
  - Gestion des conflits GPIO — cinématique du bras calibrée itérativement

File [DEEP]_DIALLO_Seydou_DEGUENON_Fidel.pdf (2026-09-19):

## RAPPORT INTERMÉDIAIRE DU PROJET :

## DEEP

### DEGUENON Fidel

### DIALLO Seydou Idrissa

ENCADRANT :

BOUVIER Thierry

## Table des matières

## Introduction

Ce projet a pour objectif la conception et la réalisation d’un système mécatronique autonome capable d’identifier la couleur d’un objet (rouge, vert ou bleu) et d’assurer son
tri | automatique.
Le système repose sur l’utilisation d’un bras robotique articulé, actionné par cinq servomoteurs, permettant la manipulation et le déplacement des objets vers des zones de tri spécifiques.

L’identification de la couleur est effectuée à l’aide d’un capteur adapté, tandis que l’ensemble du processus est piloté par une unité de commande assurant la coordination entre la détection, la prise et le dépôt de l’objet.

Par ailleurs, une interface homme-machine, implémentée via un écran TFT, permet d’assurer un suivi en temps réel du fonctionnement du système, en affichant notamment les informations relatives à la détection et aux actions en cours.

## 1. Cahier des charges

### 1.1 Expression du besoin

Objectif : Automatiser le tri de petits composants en se basant sur la couleur.

Fonction principale : Identifier et déplacer des objets vers trois zones distinctes (Rouge, Vert, Bleu).

### 1.2 Description fonctionnelle (Point de vue utilisateur)

### 1.2.1 Organisation générale

Le système repose sur une architecture embarquée pilotée par une carte microcontrôleur STM32. Le programme principal est structuré autour d’une machine à états finis, permettant de gérer de manière séquentielle et cohérente les différentes phases du fonctionnement.

Les principaux éléments matériels utilisés sont :

− Un capteur de couleur et de proximité (APDS9960),
− Un écran TFT (ILI9341) pour l’interface utilisateur,
− Un bras robotique commandé par cinq servomoteurs,
− Une unité de traitement (microcontrôleur STM32).

L’ensemble du système fonctionne en boucle infinie, assurant un traitement continu des données et des actions.

### 1.2.2 Machine à états

Le comportement du système est défini par une machine à états composée de quatre états principaux :

− INIT (Initialisation)
− WAIT_APDS (Attente d’un objet)
− DECISION (Analyse de la couleur)
− TRIE (Exécution du tri)
Cette organisation permet de structurer clairement le déroulement du processus et d’assurer une transition logique entre les différentes étapes.

### 1.2.3 Description des états

Le fonctionnement du système repose sur une machine à états composée de quatre états principaux :

− INIT (Initialisation)
Le système configure et initialise les capteurs et les périphériques. Une phase de calibration est effectuée avant de passer en mode attente.
− WAIT_APDS (Attente d’objet)
Le système surveille la présence d’un objet à l’aide du capteur de proximité. Une jauge est affichée à l’écran pour guider le positionnement. Lorsque l’objet est détecté, le système passe à l’analyse.
− DECISION (Analyse)
Le système mesure les composantes rouge, verte et bleue de l’objet, puis détermine sa couleur dominante. En fonction du résultat, une position de tri est définie.
− TRIE (Trie)
Le bras robotique saisit l’objet, le déplace vers la zone correspondante à sa couleur, puis revient à sa position initiale. Le système repasse ensuite en attente.

Le fonctionnement global du système peut être résumé comme suit :

Détection de présence → Analyse de la couleur → Décision → Mouvement du bras → Retour à l’attente

### 1.3 Limites et contraintes

Contraintes | techniques | :
Le système repose sur la carte Nucleo STM32G431KB, ce qui impose des ressources limitées. Les servomoteurs nécessitent une alimentation séparée afin d’éviter les perturbations électriques. La gestion simultanée des interfaces (I2C, SPI, PWM) constitue également une contrainte de mise en œuvre.
Limites | | :
Le tri est limité à trois couleurs (rouge, vert, bleu) avec une détection basée sur une comparaison simple des valeurs RGB. La précision du bras dépend des servomoteurs (commande PWM) et l’absence de retour de position peut entraîner des imprécisions.

## 2. Composants utilisés

### 2.1 Tableau des périphériques

Cette section présente l’ensemble des composants matériels utilisés dans le projet, en précisant pour chacun leur rôle fonctionnel au sein du système, afin de mettre en évidence l’architecture globale du bras robotique et la contribution de chaque élément à son fonctionnement.

Nom ou Référence | Description / Rôle dans l'application
STM32G431KB | Cœur du système : gestion de la machine à états et génération des signaux PWM/SPI/I2C.
APDS-9960 | Capteur de proximité et de couleur. Déclenche la prise de décision via le bus I2C.
ILI9341 (LCD) | Écran de 2.4 pouces. Affiche l'interface graphique et les retours de debugging.
Servomoteurs MG996 | Actionneurs (5 au total) pour les articulations. Pilotage par rapport cyclique (PWM).

## 2.2 Affectation des ports du microcontrôleur

Cette section présente la répartition précise des broches du microcontrôleur en fonction des besoins du projet, en indiquant pour chaque pin la fonction associée (PWM, I2C, SPI, debug, etc.) afin d’assurer une organisation cohérente du hardware et de faciliter l’intégration des différents modules du bras robotique.

Pin | Fonction dans le projet
PA9 | UART2 TX (communication série vers PC)
PA10 | UART2 RX
NRST | Reset microcontrôleur
GND | Masse
PA12 | SPI / CS écran TFT (ILI9341)
PB0 | PWM Servo (axe bras)
PB7 | I2C / signal capteur APDS9960
PA15 | SPI / signal TFT (CS ou contrôle)
PB6 | I2C SCL (capteur APDS9960)
PF0 | Oscillateur / non utilisé

PF1 | Oscillateur / non utilisé
PA8 | PWM Servo (axe épaule)
PA11 | USB / communication interne
PB5 | PWM Servo (axe pince ou coude)
PB4 | GPIO libre / non utilisé
VIN | Alimentation carte
GND | Masse
NRST | Reset
5V | Alimentation périphériques
PA2 | UART2 TX (alternative selon config BSP)
PA7 | SPI (MOSI TFT)
PA6 | SPI (MISO TFT)
PA5 | SPI (SCK TFT)
PA4 | SPI / Chip Select TFT
PA3 | UART RX / GPIO
PA1 | PWM Servo
PA0 | PWM Servo
AVDD | Alimentation analogique
3V3 | Alimentation logique
PB3 | SPI / signal TFT
PB8 | LED verte (indication système ON)

## 3. Cahier de suivi

Cette section retrace l’évolution du projet au fil des séances, en précisant les tâches réalisées par chaque membre de l’équipe, les difficultés rencontrées et les actions prévues pour la suite, afin d’assurer un suivi rigoureux et une progression cohérente du développement du bras robotique.

Date | Tâches, réalisateurs, difficultés rencontrées | À faire la prochaine fois
06/03 | Choix du sujet et définition du projet de bras robotique de tri. Répartition des tâches entre Fidel DEGUENON et Seydou DIALLO. | Début de la conception du système et architecture globale
11/03 | Soudure de composants et barrettes sur la carte DEEP Purple Complete Board pour intégrer les périphériques. Difficulté : organisation du câblage et adaptation aux contraintes matérielles. (Fidel / Seydou) | Finalisation de l’intégration des périphériques
13/03 | Gestion de l’alimentation du projet avec séparation des alimentations moteurs et logique pour éviter les parasites. Difficulté : stabilité électrique du système lors des premiers tests. | Tests des communications UART et servomoteurs

18/03 | Tests de communication UART entre la carte et le terminal PC. (Fidel DEGUENON) | Intégration écran TFT
25/03 | Tests de l’écran TFT ILI9341 et affichage des données système. Début des tests PWM pour servomoteurs. Difficulté : réglage des fréquences PWM pour éviter les tremblements des servos. | Intégration des servomoteurs au bras
27/03 | Tests des servomoteurs (contrôle via timers PWM). Validation des mouvements de base du bras robotique. Difficulté : calibration des angles et synchronisation des mouvements. | Implémentation du capteur APDS9960 en I2C
01/04 | Implémentation et tests du bus I2C pour le capteur APDS9960 (couleur et proximité). Difficulté : instabilité du bus I2C et erreurs de communication avec le capteur. | Stabilisation I2C et amélioration détection
08/04 | Mise en place de la machine à états du système (INIT, WAIT_APDS, DECISION, TRIE). (Fidel DEGUENON) | Finalisation logique de tri et intégration globale
10/04 | Conception du PCB du projet et organisation des signaux des périphériques. Difficulté : choix et conflits de GPIO entre les différents modules. | Finalisation du routage PCB
22/04 | Mise en ligne du projet sur Git pour gestion de version et sauvegarde du code. (Fidel / Seydou DIALLO) | Tests globaux et optimisation du système
29/04 | Tests globaux du système et intégration complète des modules. Début de la cinématique du bras robotique (en cours). Difficultés : cinématique du bras complexe et encore en cours d’implémentation, gestion des conflits GPIO persistants. | Finalisation de la cinématique et optimisation des performances

## 4. État d'avancement et analyse

## 4.1. État d’avancement du projet

Le projet de bras robotique basé sur la Deep Purple Complete Board est actuellement bien avancé sur la partie matérielle et partiellement fonctionnel sur la partie logicielle. Réalisations matérielles :

− Mise en place de la carte Deep Purple Complete Board et intégration des différents périphériques.
− Soudure de certains composants et mise en place de barrettes de connexion pour accueillir les modules (servomoteurs, capteurs, etc.).
− Gestion de l’alimentation du système et vérification de la stabilité des tensions. − Organisation du câblage entre les différents modules afin d’assurer une meilleure lisibilité et maintenance.
− Installation des périphériques principaux sur la carte (UART, écran, modules de commande, etc.).

Réalisations logicielles :

− Tests de communication UART entre le microcontrôleur et les périphériques externes.
− Tests de communication avec un module Bluetooth pour le contrôle sans fil.
− Tests de commande des servomoteurs via des instructions simples.
− Premier déploiement de code permettant la réception et l’exécution de positions moteur.
Tests effectués :

− Test de l’alimentation des modules sans surcharge.

LM7805 (5V) : La mesure confirme que la tension est stable, permettant d'alimenter les servomoteurs et les périphériques logiques sans risque.

LF33CV (3.3V) : En tant que régulateur LDO (Low-Dropout), le LF33CV assure une tension précise pour le cœur du STM32. La valeur mesurée est conforme aux spécifications du fabricant.

− Vérification de la transmission UART.

Le test de l’UART (Universal Asynchronous Receiver-Transmitter) constitue l’étape initiale et essentielle de la validation de la chaîne de transmission. L’objectif est de vérifier l’intégrité de la liaison bidirectionnelle entre la carte STM32 et le PC, afin de s’assurer que les données transmises sont correctement reçues et interprétées par les deux systèmes.

Dans notre cas, la configuration de l’UART est réalisée sur la broche PA2, et c’est à ce niveau que nous avons vérifié le bon fonctionnement de la communication. Pour cela, nous avons visualisé à l’oscilloscope les premiers caractères envoyés (Hi) depuis la carte STM32 vers le PC, via le logiciel Docklite.

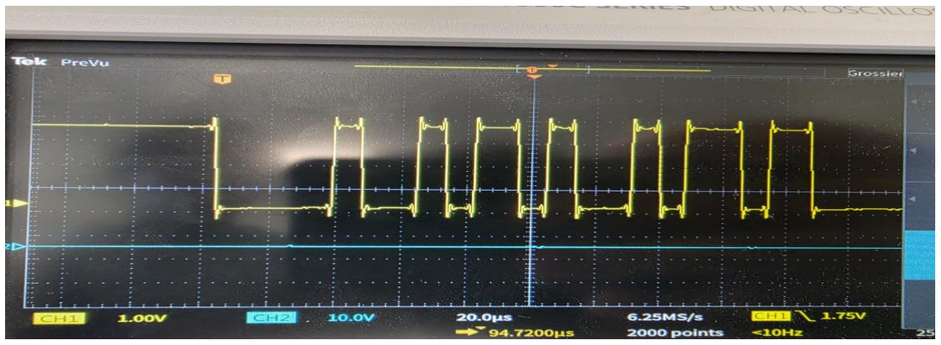
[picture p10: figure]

− Test de communication avec l’écran (affichage basique).
Le test de l’écran a consisté à utiliser la fonction de démonstration intégrée, permettant d’afficher une simple chaîne de caractères. Cette étape a confirmé que l’écran s’initialise correctement et que la communication avec la carte STM32 fonctionne comme prévu.

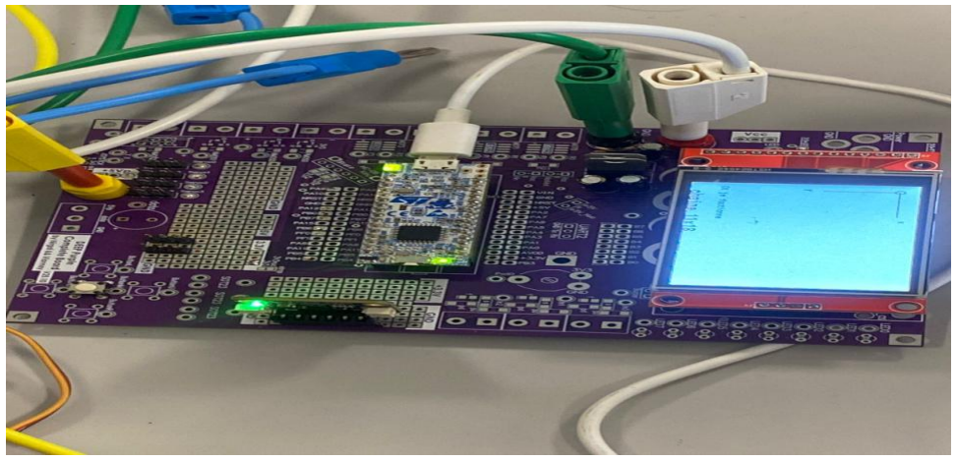
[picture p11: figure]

− Test de réponse des servomoteurs à des commandes simples.
Le test du servomoteur a consisté à vérifier la génération correcte des impulsions PWM à partir des broches configurées sur les canaux des timers. À l’oscilloscope, nous avons observé les signaux PWM produits par la carte STM32, ce qui nous a permis de confirmer que les largeurs d’impulsion variaient correctement en fonction des commandes envoyées. Ce test valide ainsi la capacité du microcontrôleur à piloter le servo via ses timers.

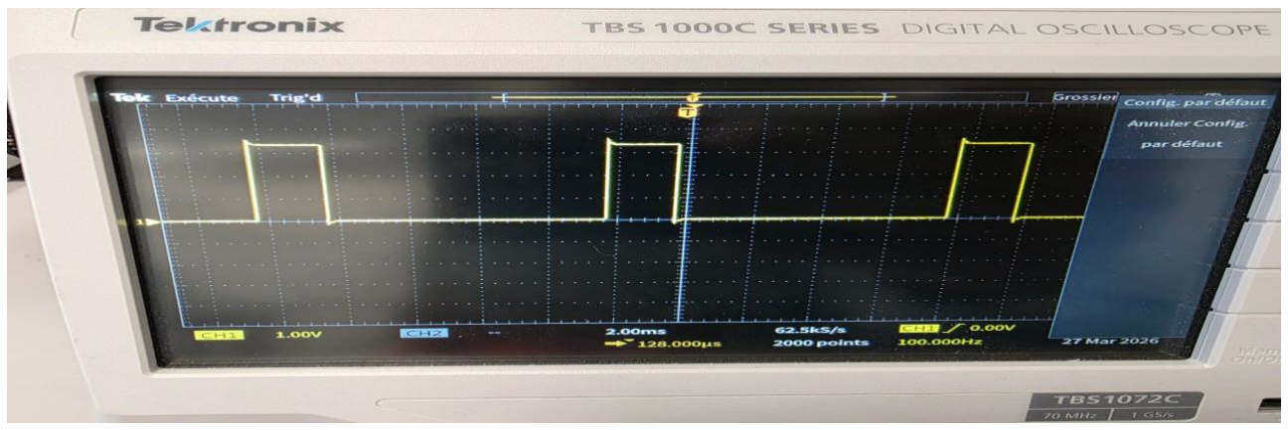
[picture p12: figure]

− Test de la communication I2C1.

Le test du capteur APDS9960 a consisté à vérifier le bon fonctionnement de la communication via le bus I2C1. Pour cela, nous avons observé les signaux sur les deux lignes I2C :

− SDA (PB7) : signal de données
− SCL (PA15) : signal d’horloge

L’analyse à l’oscilloscope a permis de confirmer la présence des trames I2C lors des échanges entre la carte STM32 et le capteur, validant ainsi l’initialisation correcte du bus et la communication avec l’APDS9960.

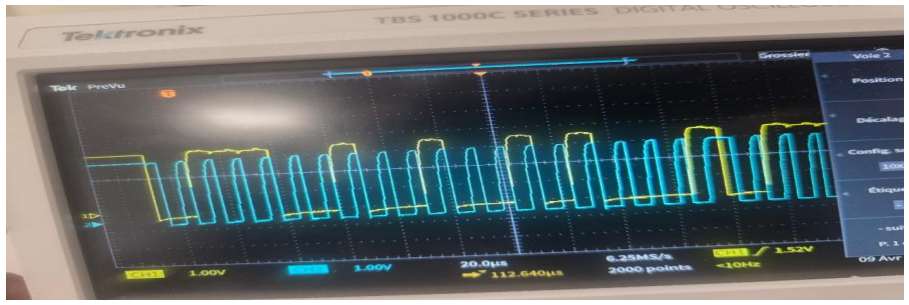
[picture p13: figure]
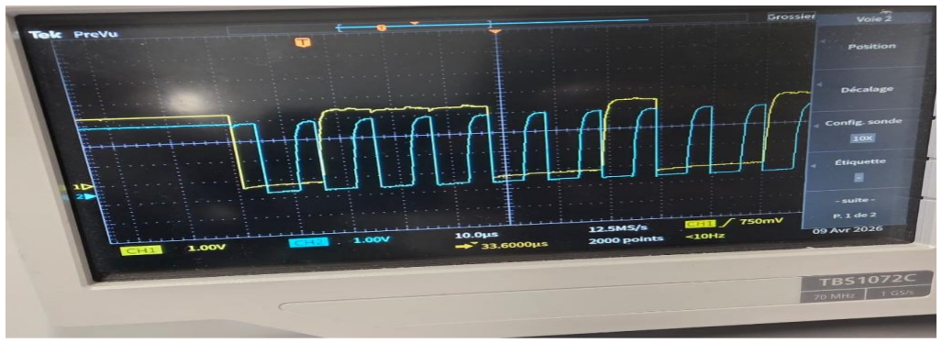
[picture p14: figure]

## 4.2. Points restant à terminer

Malgré l’avancement du projet, certaines parties restent à finaliser :

− Intégration complète de tous les servomoteurs dans un mouvement coordonné du bras robotique.
− Amélioration du code de contrôle pour permettre des séquences de mouvements (actions groupées).
− Stabilisation de la communication Bluetooth pour éviter les pertes de données. − Finalisation de l’interface de commande (logiciel ou application).
− Optimisation de la gestion énergétique (réduction des chutes de tension lors des mouvements simultanés).
− Tests de charge complète du système (plusieurs moteurs en fonctionnement simultané).

## 4.3. Analyse du travail réalisé

Analyse du hardware :

Si la partie matérielle devait être refaite, plusieurs améliorations seraient envisagées :

− Meilleure planification du câblage dès le départ : le prototypage initial a entraîné des fils dispersés, rendant la maintenance difficile.
− Utilisation de connecteurs plus robustes et standardisés pour éviter les problèmes de faux contacts.
− Ajout d’un PCB intermédiaire ou d’une plaque de distribution d’alimentation afin de mieux gérer les différents modules.
− Séparation plus claire entre les circuits de puissance (moteurs) et les circuits logiques pour réduire les perturbations.
Analyse du logiciel :

− Le code actuel fonctionne pour des tests simples, mais manque de structure pour des mouvements complexes.
− L’utilisation de commandes basiques via UART/Bluetooth est efficace, mais pourrait être remplacée par un protocole plus structuré (type trames ou API de commande).
− L’architecture logicielle pourrait être améliorée en utilisant une approche modulaire (gestion séparée des moteurs, communication, et capteurs). Problèmes rencontrés :

− Instabilité de l’alimentation lors de l’activation simultanée de plusieurs servomoteurs.
− Difficultés de synchronisation entre les différents modules.
− Complexité du câblage rendant certains tests longs à diagnostiquer.
− Besoin de nombreux tests itératifs pour stabiliser les communications UART et Bluetooth.

## 5. Software

5.1 Architecture logicielle

Le programme est basé sur une Machine à États Finis (FSM) afin d’assurer un comportement structuré et déterministe du robot.

Les principaux états sont :

− INIT : initialisation des périphériques (PWM, SPI, I2C, horloge). − WAIT_APDS : détection d’un objet via le capteur de proximité.
− DECISION : analyse RGB pour identifier la couleur.
− TRIE : exécution du mouvement de tri via PWM.

Cette architecture permet une exécution simple, lisible et fiable des différentes étapes du processus.

5.2 Tests et validations

Validés :

− Communication UART fonctionnelle pour le monitoring. − Affichage TFT opérationnel.
− Capteur de proximité stable.
− Enchaînement correct des états FSM.

À effectuer :

− Tests de précision lors de la phase de dépose.
− Analyse de l’influence de la lumière sur le capteur couleur. − Tests de stabilité en fonctionnement continu.

5.3 Analyse rapide

L’architecture FSM est adaptée au système embarqué et facilite le contrôle du robot. Cependant, le système reste perfectible, notamment sur la robustesse des mesures couleur et la précision des mouvements.

## 6. Compléments envisagés

Pour répondre aux exigences de l'unité d'enseignement et valoriser notre travail, nous avons sélectionné les compléments suivants (total de 7 points visés) :

− B- Routage de PCB avec Nucleo (3 pts) : Conception d'une carte d'interface (Shield) pour fiabiliser la connectique des servomoteurs et l'alimentation de puissance.
− G- Gestion de version Git (1 pt) : Utilisation d'un dépôt distant pour assurer la traçabilité des modifications et faciliter le travail collaboratif. Lien : https://github.com/Fidel-Dgn/stm32-projet-robotic-arm.git
− E- Mesure de conso et d’énergie (2 pts) : Analyse de la consommation du système en régime statique vs dynamique pour évaluer l'autonomie potentielle sur batterie.
− I- Impact environnemental (2 pts): analyse de cycle de vie du bras robotisé de trie − T- Jeu de tests (1 pt) : Développement d'une routine logicielle de validation
| automatique des butées des servomoteurs lors de la mise sous tension.

Annexe B : Conception et Routage du PCB

B.1 Présentation du schéma électrique

Le schéma a été réalisé sous Altium Designer/KiCad dans l'objectif d'interfacer la carte Nucleo STM32G431KB avec les périphériques (servomoteurs, capteur APDS9960, écran).

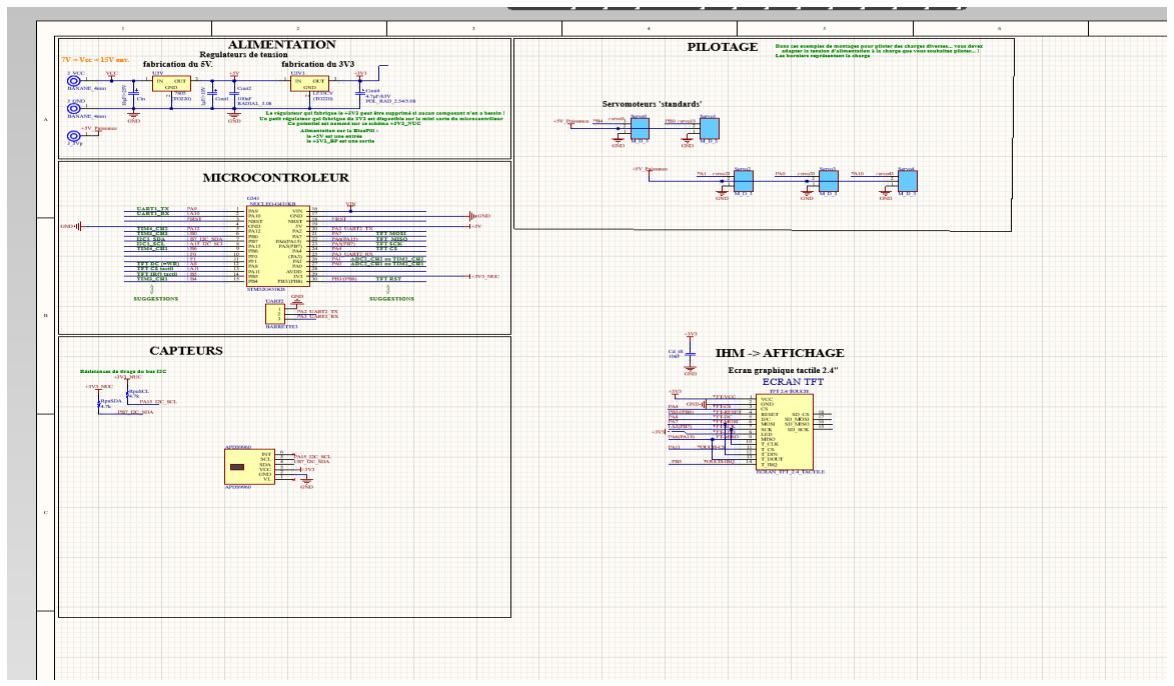
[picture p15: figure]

- Rôle des composants/périphériques :
- Connecteurs de puissance : Utilisés pour distribuer l'alimentation 5V/6V aux servomoteurs, isolée de l'alimentation logique pour éviter les chutes de tension.
- Condensateurs de découplage (100nF/10µF) : Placés au plus près des broches d'alimentation des capteurs pour filtrer le bruit haute fréquence.
- Buses I2C/SPI : Les résistances de tirage (pull-up) ont été dimensionnées pour garantir l'intégrité du bus I2C vers le capteur APDS9960 malgré les longueurs de pistes.

B.2 Routage du PCB (Vue 2D)

La vue ci-dessous présente le routage final, avec les plans de masse masqués pour une meilleure lisibilité des pistes de signal.

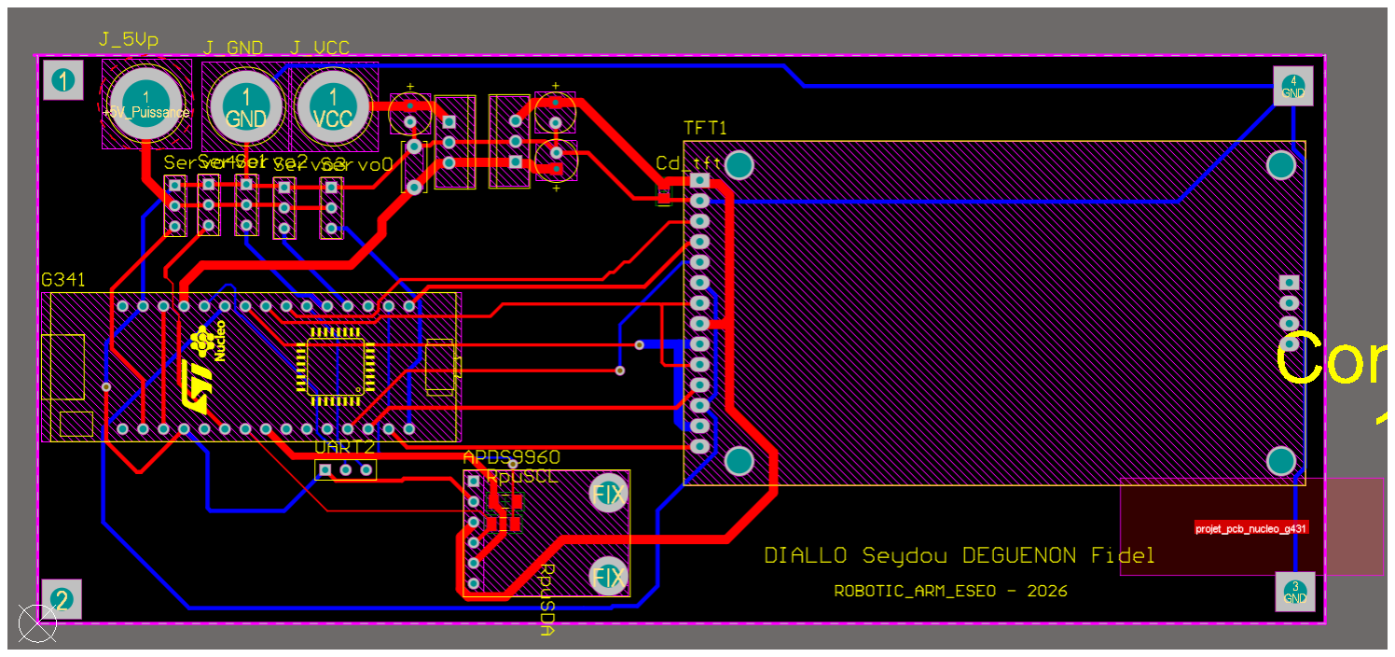
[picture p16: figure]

- Stratégie de routage : Les pistes de puissance (servomoteurs) ont été routées avec une largeur de [X] mm pour supporter le courant d'appel. Les signaux numériques sensibles ont été protégés des zones bruyantes (PWM moteurs).

B.3 Vues 3D du PCB

Le design final assure une intégration mécanique optimale pour le bras robotique.

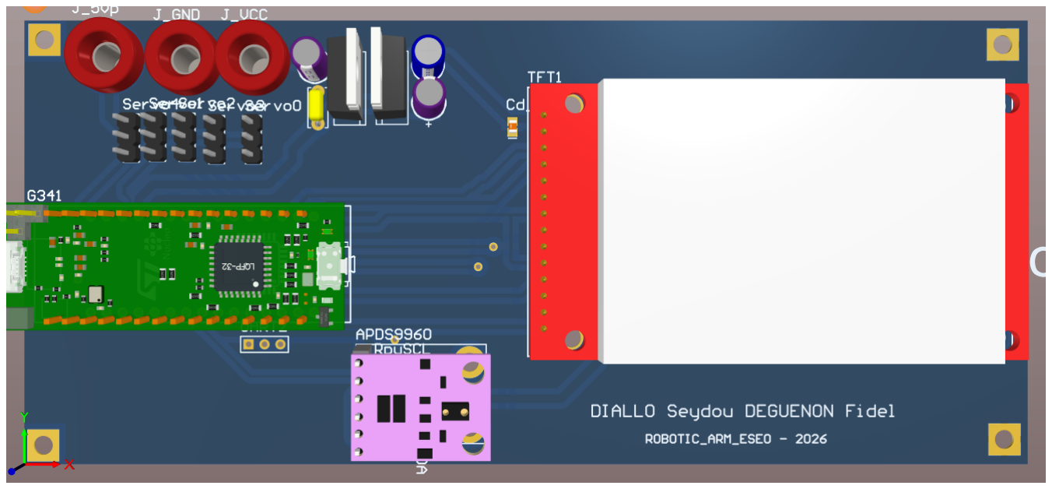
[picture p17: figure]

B.4 Difficultés rencontrées

La conception de ce PCB a soulevé plusieurs défis techniques :

- Densité de routage : Le grand nombre de broches de la Nucleo a nécessité une gestion précise des vias pour éviter les croisements de pistes.
- Gestion des courants : La gestion des courants des 5 servomoteurs simultanés a imposé d'élargir les pistes d'alimentation pour éviter tout échauffement excessif.

- Contraintes d'encombrement : L'intégration du support pour le capteur APDS9960 à proximité des moteurs a nécessité un routage spécifique pour limiter les interférences électromagnétiques sur le bus I2C.

B.5 Estimation du coût de production

Conformément aux consignes, nous avons généré les fichiers Gerber et simulé une commande auprès du fabricant JLCPCB pour une quantité de 5 exemplaires.

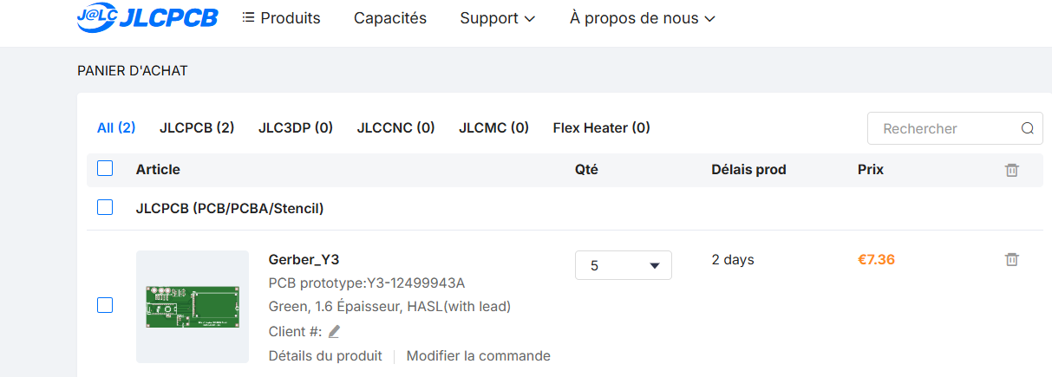
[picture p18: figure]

- Coût estimé : 7,36 € (hors frais de port).
- Note : Cette estimation est fournie à titre indicatif pour valider la faisabilité industrielle du prototype.

## Conclusion

Ce projet de bras robotique illustre une démarche complète d’ingénierie, allant de la conception matérielle à l’implémentation logicielle, jusqu’à la validation expérimentale. L’intégration d’une architecture basée sur une machine à états finis a permis d’assurer un fonctionnement structuré, fiable et évolutif du système.

Au-delà des résultats obtenus, ce projet met en évidence les défis concrets des systèmes embarqués, notamment en termes de gestion de l’énergie, de précision des capteurs et de coordination des actionneurs. Les solutions apportées, ainsi que les axes d’amélioration identifiés, témoignent d’une réelle capacité d’analyse et d’adaptation face aux contraintes techniques.

Enfin, ce travail constitue une base solide pour des développements futurs, avec des perspectives d’optimisation tant sur le plan matériel que logiciel. Il reflète ainsi une approche rigoureuse et cohérente de la conception d’un système robotique complet.

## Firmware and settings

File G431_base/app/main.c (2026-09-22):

/**
 *******************************************************************************
 * @file 	main.c
 * @author 	jjo
 * @date 	Mar 29, 2024
 * @brief	Fichier principal de votre projet sur carte Nucléo STM32G431KB
 *******************************************************************************
 */

#include "config.h"
#include "stm32g4_sys.h"

#include "stm32g4_systick.h"
#include "stm32g4_gpio.h"
#include "stm32g4_uart.h"
#include "stm32g4_utils.h"
#include "APDS9960/stm32g4_apds9960.h"
#include "stm32g4_timer.h"
#include "tft_ili9341/stm32g4_ili9341.h"
#include "tft_ili9341/stm32g4_fonts.h"
#include "tft_ili9341/stm32g4_xpt2046.h"
#include <servo.h>
#include <stdio.h>

#define PROXIMITY_THRESHOL 150
#define BLINK_DELAY		100	//ms
void TestCharReceiveUart(uint8_t c);
void Test_Ecran(void);
void example_rgb_read(void);


// Couleurs personnalisées pour l'interface
#define COLOR_ESEO          0x0194  // Bleu ESEO
#define COLOR_BG            ILI9341_COLOR_WHITE
#define COLOR_TEXT          ILI9341_COLOR_BLACK
#define COLOR_BAR_BG        0xDEDB  // Gris clair pour le fond des barres


// Positions de la Base (rotation)
#define BASE_INIT_A    90
#define BASE_X_BLEU    45
#define BASE_Y_ROUGE   135
#define BASE_Z_VERT    180

// Positions des autres articulations pour "saisir" (exemples)
#define SHOULDER_POS   60
#define ELBOW_POS      40
#define WRIST_POS      90
#define GRIPPER_OPEN   10
#define GRIPPER_CLOSE  80

TIM_HandleTypeDef htim1;
TIM_HandleTypeDef htim2;
TIM_HandleTypeDef htim3;

uint16_t target_base_angle = BASE_INIT_A;



// Suivi de l'état pour rafraîchissement intelligent

uint16_t proximity_bar_width = 0;


/*typedef enum {
    INIT,
    WAIT_APDS,
    DECISION,
    TRIE
} SystemState;


SystemState state = INIT;   // variable globale
SystemState last_state = -1;*/


typedef enum {    // Nouvel état : attend l'appui sur l'écran
    INIT,
    WAIT_APDS,
    DECISION,
    TRIE
} SystemState;

SystemState state = INIT; // On commence en veille
SystemState last_state = -1;

// Structure pour définir la zone du bouton Start
typedef struct {
    uint16_t x;
    uint16_t y;
    uint16_t w;
    uint16_t h;
} TouchButton;

TouchButton startBtn = {80, 140, 160, 60}; // Bouton centré

bool isButtonPressed(int16_t touchX, int16_t touchY, TouchButton btn) {
    return (touchX >= btn.x && touchX <= (btn.x + btn.w) &&
            touchY >= btn.y && touchY <= (btn.y + btn.h));
}



/**
  * @brief  Point d'entrée de votre application
  */
int main(void)
{
	/* Cette ligne doit rester la première de votre main !
	 * Elle permet d'initialiser toutes les couches basses des drivers (Hardware Abstraction Layer),
	 * condition préalable indispensable à l'exécution des lignes suivantes.
	 */
	uint8_t proximity = 0;   // Pour la lecture de proximité (0-255)
	uint16_t r=0, g=0, b=0;  // Pour les lectures de couleurs
	HAL_Init();
	ILI9341_Init();


	/* Initialisation des périphériques utilisés dans votre programme */
	BSP_GPIO_enable();
	BSP_UART_init(UART2_ID,115200);


	/*
	APDS9960_init();
	APDS9960_getMode();
	APDS9960_setMode(ALL, ON);
	APDS9960_enablePower();
	APDS9960_enableLightSensor(interrupts);
	APDS9960_enableProximitySensor(interrupts);*/
	/* Indique que les printf sont dirigés vers l'UART2 */
	BSP_SYS_set_std_usart(UART2_ID, UART2_ID, UART2_ID);


	// Dans ton main, avant le while(1)
	APDS9960_init();
	APDS9960_enablePower();
	// On configure le gain au minimum pour éviter la saturation (8224)
	APDS9960_setAmbientLightGain(AGAIN_1X);




	/* Initialisation du port de la led Verte (carte Nucleo) */
	BSP_GPIO_pin_config(LED_GREEN_GPIO, LED_GREEN_PIN, GPIO_MODE_OUTPUT_PP,GPIO_NOPULL,GPIO_SPEED_FREQ_HIGH,GPIO_NO_AF);

	/* Hello student */
	printf("Hi <Student>, can you read me?\n");

	//heartbeat();
	SERVO_init();



	//fonction test Ecran
	//Test_Ecran();
	//ILI9341_Init();
	//ILI9341_demo();
	//ILI9341_Puts(10,200,"OK je foctionne..",&Font_7x10,ILI9341_COLOR_BLACK,ILI9341_COLOR_WHITE);
	//Test Demo APDS
	//APDS9960_demo_RGB();

	//test

	/* Tâche de fond, boucle infinie, Infinite loop,... quelque soit son nom vous n'en sortirez jamais */
//	while (1)
//	{
		//example_rgb_read();

		/*

		SERVO_process_test(TIMER3_ID, TIM_CHANNEL_1);PB4
		SERVO_process_test(TIMER3_ID, TIM_CHANNEL_3);PB0
		//SERVO_process_test(TIMER3_ID, TIM_CHANNEL_4);
		SERVO_process_test(TIMER1_ID, TIM_CHANNEL_3);PA10
		SERVO_process_test(TIMER2_ID, TIM_CHANNEL_1);PA0
		SERVO_process_test(TIMER2_ID, TIM_CHANNEL_2);PA1

		switch (state)
		{
		    case INIT:
		        // Code
		    	APDS9960_enablePower();
		    	APDS9960_enableLightSensor(interrupts);
		    	APDS9960_enableProximitySensor(interrupts);
		        break;

		    case WAIT_APDS:
		        // Code
		        break;

		    case DECISION:
		    	// Code
		    	APDS9960_disablePower();
		    	break;

		    case TRIE:

		    	break;

		    default:
		        // Code si aucun case ne correspond
		        break;
		}
	*/
		while (1)
		{
		    // --- 1. RAFRAÎCHISSEMENT DE L'ÉCRAN (Seulement si l'état change) ---
		    if (state != last_state)
		    {
		        // Effacer la zone de travail centrale
		        ILI9341_DrawFilledRectangle(0, 40, 319, 239, COLOR_BG);

		        // Dessiner le Header (Bandeau titre)
		        ILI9341_DrawFilledRectangle(0, 0, 319, 35, COLOR_ESEO);
		        ILI9341_Puts(10, 8, "ROBOTIC ARM PROJECT - ESEO", &Font_11x18, ILI9341_COLOR_WHITE, COLOR_ESEO);

		        // Afficher le nom de l'état actuel en gros
		        char state_str[20];
		        switch(state) {
		            case INIT:      sprintf(state_str, "INITIALISATION"); break;
		            case WAIT_APDS: sprintf(state_str, "ATTENTE OBJET "); break;
		            case DECISION:  sprintf(state_str, "ANALYSE...     "); break;
		            case TRIE:      sprintf(state_str, "TRI EN COURS   "); break;
		        }
		        ILI9341_Puts(10, 50, state_str, &Font_16x26, ILI9341_COLOR_BLUE, COLOR_BG);

		        last_state = state;
		    }

		    // --- 2. LOGIQUE ET AFFICHAGE DYNAMIQUE ---
		    switch (state)
		    {
		        case INIT:
		            ILI9341_Puts(10, 100, "Calibration capteurs...", &Font_7x10, COLOR_TEXT, COLOR_BG);
		            APDS9960_init();
		            APDS9960_enablePower();
		            APDS9960_enableProximitySensor(false);
		            APDS9960_enableLightSensor(false);
		            HAL_Delay(1000);
		            state = WAIT_APDS;
		            break;

		        case WAIT_APDS:
		            APDS9960_readProximity(&proximity);

		            // Affichage d'une jauge de proximité
		            ILI9341_Puts(10, 100, "Distance objet:", &Font_7x10, COLOR_TEXT, COLOR_BG);
		            ILI9341_DrawRectangle(10, 115, 210, 130, ILI9341_COLOR_BLACK); // Contour
		            ILI9341_DrawFilledRectangle(11, 116, 209, 129, COLOR_BAR_BG);  // Fond

		            // Largeur proportionnelle (proximity va de 0 à 255)
		            uint16_t bar_w = (proximity * 198) / 255;
		            ILI9341_DrawFilledRectangle(11, 116, 11 + bar_w, 129, ILI9341_COLOR_BLUE);

		            if (proximity > PROXIMITY_THRESHOL) {
		                state = DECISION;
		            }
		            break;

		        case DECISION:
		                    // 1. Lecture des capteurs
		                    APDS9960_readRedLight(&r);
		                    APDS9960_readGreenLight(&g);
		                    APDS9960_readBlueLight(&b);

		                    // 2. Affichage des valeurs brutes pour le débug
		                    ILI9341_printf(10, 100, &Font_7x10, ILI9341_COLOR_RED, COLOR_BG, "Rouge: %d  ", r);
		                    ILI9341_printf(10, 115, &Font_7x10, ILI9341_COLOR_GREEN, COLOR_BG, "Vert : %d  ", g);
		                    ILI9341_printf(10, 130, &Font_7x10, ILI9341_COLOR_BLUE, COLOR_BG, "Bleu : %d  ", b);

		                    // Contour du carré de prévisualisation
		                    ILI9341_DrawRectangle(220, 90, 300, 150, ILI9341_COLOR_BLACK);

		                    // 3. Logique de décision de couleur
		                    // Test ROUGE
		                    if (r > g && r > b) {
		                        ILI9341_DrawFilledRectangle(221, 91, 299, 149, ILI9341_COLOR_RED);
		                        ILI9341_Puts(10, 160, "RESULTAT: ROUGE", &Font_11x18, ILI9341_COLOR_RED, COLOR_BG);
		                        HAL_Delay(10000);
		                        target_base_angle = BASE_Y_ROUGE;
		                        state = TRIE;
		                    }
		                    // Test VERT
		                    else if (g > r && g > b) {
		                        ILI9341_DrawFilledRectangle(221, 91, 299, 149, ILI9341_COLOR_GREEN);
		                        ILI9341_Puts(10, 160, "RESULTAT: VERT ", &Font_11x18, ILI9341_COLOR_GREEN, COLOR_BG);
		                        HAL_Delay(10000);

		                        target_base_angle = BASE_Z_VERT;
		                        state = TRIE;
		                    }
		                    // --- NOUVEAU : Test BLEU ---
		                    else if (b > r && b > g) {
		                        ILI9341_DrawFilledRectangle(221, 91, 299, 149, ILI9341_COLOR_BLUE);
		                        ILI9341_Puts(10, 160, "RESULTAT: BLEU  ", &Font_11x18, ILI9341_COLOR_BLUE, COLOR_BG);
		                        HAL_Delay(10000);

		                        target_base_angle = BASE_X_BLEU;
		                        state = TRIE;
		                    }
		                    // Si aucune couleur ne domine clairement ou si c'est trop sombre
		                    else {
		                        state = WAIT_APDS;
		                    }
		                    break;

		        case TRIE:

		       	   ILI9341_Puts(10, 200, "Tri en cours...", &Font_7x10, ILI9341_COLOR_GRAY, COLOR_BG);
		       	   //SERVO_set_angle(TIMER3_ID, TIM_CHANNEL_1, BASE_INIT_A);
		       	   SERVO_set_angle(TIMER2_ID, TIM_CHANNEL_2, GRIPPER_CLOSE);
		       	 /*
		            // --- ÉTAPE 1 : ALLER CHERCHER L'OBJET (Position A) ---
		            // On s'assure que la base est bien à A (90°)
		            SERVO_set_angle(TIMER3_ID, TIM_CHANNEL_1, BASE_INIT_A);
		            // On baisse le bras et on ferme la pince
		            SERVO_set_angle(TIMER3_ID, TIM_CHANNEL_3, SHOULDER_POS);
		            SERVO_set_angle(TIMER1_ID, TIM_CHANNEL_3, ELBOW_POS);
		            HAL_Delay(500);
		            SERVO_set_angle(TIMER2_ID, TIM_CHANNEL_2, GRIPPER_CLOSE); // Fermer pince
		            HAL_Delay(500);

		            // --- ÉTAPE 2 : PIVOTER VERS LA DESTINATION (X, Y ou Z) ---
		            // On lève un peu le bras pour ne pas traîner l'objet
		            SERVO_set_angle(TIMER3_ID, TIM_CHANNEL_3, 90);
		            HAL_Delay(300);
		            // On tourne la base
		            SERVO_set_angle(TIMER3_ID, TIM_CHANNEL_1, target_base_angle);
		            HAL_Delay(800);

		            // --- ÉTAPE 3 : POSER ET REVENIR ---
		            SERVO_set_angle(TIMER2_ID, TIM_CHANNEL_2, GRIPPER_OPEN); // Ouvrir pince
		            HAL_Delay(500);

		            // REVENIR À LA POSITION INITIALE A (Tout le bras se remet droit)
		            SERVO_set_angle(TIMER3_ID, TIM_CHANNEL_1, BASE_INIT_A);
		            SERVO_set_angle(TIMER3_ID, TIM_CHANNEL_3, 90);
		            SERVO_set_angle(TIMER1_ID, TIM_CHANNEL_3, 90);
		            SERVO_set_angle(TIMER2_ID, TIM_CHANNEL_1, 90);
		            HAL_Delay(800);
		            */

		            state = WAIT_APDS;
		            break;

		        default: state = INIT; break;
		    }

		    HAL_Delay(1000); // Limite le taux de rafraîchissement pour l'I2C/SPI
		}






}



void write_LED(bool b)
	{
		HAL_GPIO_WritePin(LED_GREEN_GPIO, LED_GREEN_PIN, b);
	}

bool char_received(uart_id_t uart_id)
	{
		if( BSP_UART_data_ready(uart_id) )	/* Si un caractère est reçu sur l'UART 2*/
		{
			/* On "utilise" le caractère pour vider le buffer de réception */
			BSP_UART_get_next_byte(uart_id);
			return true;
		}
		else
			return false;
	}

	void heartbeat(void)
	{
		while(! char_received(UART2_ID) )
		{
			write_LED(true);
			HAL_Delay(50);
			write_LED(false);
			HAL_Delay(1500);
		}
	}


	void TestCharReceiveUart(uint8_t c){

			// reception et envoie sur la broche PA5 de la carte nucleo de chaque bit du caractere envoyer par l'uart
			for(int i = 0; i < 8; i++)
				{
					if( (c >> i) & 1 ){

						HAL_GPIO_WritePin(GPIOA, GPIO_PIN_5, GPIO_PIN_SET);
					}else{
						HAL_GPIO_WritePin(GPIOA, GPIO_PIN_5, GPIO_PIN_RESET);
					}
					HAL_Delay(1); // 1 ms → visible à l’oscillo

				}

			// petit espace entre caractères
			HAL_Delay(5);


	}

	void Test_Ecran(void){
		ILI9341_Init();

		 //Test couleurs
		ILI9341_Fill(ILI9341_COLOR_RED);
		HAL_Delay(500);
		ILI9341_Fill(ILI9341_COLOR_GREEN);
		HAL_Delay(500);
		ILI9341_Fill(ILI9341_COLOR_BLUE);
		HAL_Delay(500);

		// Test dessin
		ILI9341_DrawLine(0,0,200,200,ILI9341_COLOR_WHITE);
		ILI9341_DrawRectangle(10,10,100,60,ILI9341_COLOR_YELLOW);
		ILI9341_DrawFilledCircle(120,160,30,ILI9341_COLOR_RED);

		// Test texte
		ILI9341_Puts(150,50,"OK je foctionne..",&Font_7x10,ILI9341_COLOR_BLACK,ILI9341_COLOR_WHITE);
	}


	// Exemple de lecture RGB basique
	void example_rgb_read(void) {
	    uint16_t ambient, red, green, blue;

	    // NE PAS réactiver le capteur ici, c'est déjà fait dans le main
	    APDS9960_readAmbientLight(&ambient);
	    APDS9960_readRedLight(&red);
	    APDS9960_readGreenLight(&green);
	    APDS9960_readBlueLight(&blue);

	    // Si les valeurs restent à 8224, affiche aussi la Proximité pour voir si le capteur répond
	    printf("A:%d R:%d G:%d B:%d\n", ambient, red, green, blue);

	    HAL_Delay(200); // Laisse souffler l'I2C
	}

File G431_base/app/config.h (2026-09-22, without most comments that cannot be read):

/**
 *******************************************************************************
 * @file 	config.h
 * @author 	jjo
 * @date 	Mar 29, 2024
 * @brief	Fichier principal de configuration de votre projet sur carte Nucléo STM32G431KB.
 * 			Permet d'activer les différents modules logiciels à votre disposition.
 *******************************************************************************
 */

/* Define to prevent recursive inclusion -------------------------------------*/
#ifndef CONFIG_H_
#define CONFIG_H_


/* Includes ------------------------------------------------------------------*/
#include "stm32g4xx_hal.h"

/* Defines -------------------------------------------------------------------*/
#define LED_GREEN_PIN 		GPIO_PIN_8
#define LED_GREEN_GPIO 		GPIOB

#define UART2_ON_PA3_PA2
#define UART1_ON_PA10_PA9

#define USE_BSP_TIMER		1
#define USE_BSP_EXTIT		1

#define USE_RTC				0

#define USE_ADC				0
	/* Configuration pour activer les entrées analogiques souhaitées */
	#define USE_IN1		1 //Broche correspondante: PA0
	#define USE_IN2		1 //Broche correspondante: PA1
	#define USE_IN3		0 //Broche correspondante: PA6
	#define USE_IN4		0 //Broche correspondante: PA7
	#define USE_IN10	0 //Broche correspondante: PF1 /!\ Broche indisponible sur g431 sauf si SB11 et pas SB10 (petits pads à souder sur la carte)
	#define USE_IN13	0 //Broche correspondante: PA5
	#define USE_IN17	0 //Broche correspondante: PA4

#define USE_DAC				0

/*------------------Afficheurs------------------*/
#define USE_ILI9341			1
#if USE_ILI9341
	#define USE_XPT2046			1
	#define USE_FONT7x10		1
	#define USE_FONT11x18		1
	#define USE_FONT16x26		1
#endif

#define USE_EPAPER			0
#define USE_WS2812			0 // Matrice de led

/*------------------Capteurs------------------*/
#define USE_MPU6050			0
#define USE_APDS9960		1
#define USE_BMP180			0
#define USE_BH1750FVI		0
#define USE_DHT11			0
#define USE_DS18B20			0
#define USE_YX6300			0 // Lecteur MP3
#define USE_MATRIX_KEYBOARD 0 // Clavier matriciel
#define USE_HCSR04			0
#define USE_GPS				0 // GPS
#define USE_LD19			0 // Lidar --> veuillez aussi activer USE_ILI9341, USE_XPT2046, USE_FONT7x10 et USE_FONT16x26 si vous voulez utiliser display_ld19.c
#define USE_NFC03A1			0 // Shield NFC
#define USE_VL53L0			0
#if USE_VL53L0
	#define VL53L0X_I2C			I2C1
	#define VL53_NB				1 // La version actuelle du driver ne peut traiter que 8 capteurs au maximum

	#define VL_0				GPIOA, GPIO_PIN_0 // Pin de reset
	//#define VL_1				GPIOD, GPIO_PIN_3
	//#define VL_2				GPIOE, GPIO_PIN_10
#endif

/*------------------Expanders------------------*/
#define USE_MCP23017		0 // GPIO expander qui communique en i2C
#define USE_MCP23S17		0 // GPIO expander qui communique en SPI
#define USE_SD_CARD			0

/*------------------Actionneurs------------------*/
#define USE_MOTOR_DC		0



#if USE_MLX90614 || USE_MPU6050	|| USE_APDS9960	 || USE_BH1750FVI || USE_BMP180 || USE_MCP23017 || USE_VL53L0 // Liste des modules utilisants le périphérique I2C
	#define USE_I2C				1
#else
	#ifndef USE_I2C
		#define USE_I2C				0
	#endif
#endif
#define I2C_TIMEOUT			5//ms

#if USE_ILI9341 || USE_SD_CARD || USE_MCP23S17 || USE_EPAPER
	#define USE_SPI				1
#else
	#ifndef USE_SPI
		#define USE_SPI				0
	#endif
#endif

#define USE_TESTBOARD				0


#endif /* CONFIG_H_ */

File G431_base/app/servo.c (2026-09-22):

#include "config.h"
#include "stm32g4_uart.h"
#include "stm32g4_utils.h"
#include <servo.h>
#include "stm32g4_timer.h"


// N'oubliez pas les handles externes pour la macro HAL
extern TIM_HandleTypeDef htim1;
extern TIM_HandleTypeDef htim2;
extern TIM_HandleTypeDef htim3;

// Votre implémentation de SERVO_set_angle comme vu précédemment...

// Importation des handles définis ailleurs dans le projet
#define PERIOD_TIMER 10 //ms

static uint16_t current_position;

void SERVO_process_test(timer_id_t timer_id,uint16_t TIM_CHANNEL_x){

	SERVO_set_position(timer_id,TIM_CHANNEL_x,0);
	HAL_Delay(5000);
	SERVO_set_position(timer_id,TIM_CHANNEL_x,100);
	HAL_Delay(5000);
	SERVO_set_position(timer_id,TIM_CHANNEL_x,50);
	HAL_Delay(5000);
	SERVO_set_position(timer_id,TIM_CHANNEL_x,100);


	 static uint16_t position = 50;
	 if( BSP_UART_button(UART2_ID) ){

		 //si appui bouton
		 position = (position > 99)?0:(position+5); //de 0 à 100%, par pas de 5%
		 SERVO_set_position(timer_id,TIM_CHANNEL_x,position);
	 }

}


void SERVO_init(void){

		//initialisation et lancement du timer1 à une période de 10 ms
		BSP_TIMER_run_us(TIMER3_ID, PERIOD_TIMER*2000, false); //20000us = 20ms*
		BSP_TIMER_run_us(TIMER1_ID, PERIOD_TIMER*2000, false); //20000us = 20ms*
		BSP_TIMER_run_us(TIMER2_ID, PERIOD_TIMER*2000, false); //20000us = 20ms*

				/*
				 * SERVO_process_test(TIMER3_ID, TIM_CHANNEL_1);PB4
				SERVO_process_test(TIMER3_ID, TIM_CHANNEL_3);PB0
				SERVO_process_test(TIMER1_ID, TIM_CHANNEL_3);PA10
				SERVO_process_test(TIMER2_ID, TIM_CHANNEL_1);PA0
				SERVO_process_test(TIMER2_ID, TIM_CHANNEL_2);PA1*/


		//activation du signal PWM sur les canaux
		while(1){
			/*BSP_TIMER_enable_PWM(TIMER3_ID, TIM_CHANNEL_1, 125, true, false);
			HAL_Delay(3000);
			BSP_TIMER_enable_PWM(TIMER3_ID, TIM_CHANNEL_1, 25, true, false);
			HAL_Delay(3000);
			BSP_TIMER_enable_PWM(TIMER3_ID, TIM_CHANNEL_3, 100, false, false); //fermeture
			HAL_Delay(3000);
			BSP_TIMER_enable_PWM(TIMER3_ID, TIM_CHANNEL_3, 25, false, false); // ouverture
			HAL_Delay(3000);
			BSP_TIMER_enable_PWM(TIMER3_ID, TIM_CHANNEL_3, 50, false, false); // bras
			HAL_Delay(3000);*/
			//BSP_TIMER_enable_PWM(TIMER1_ID, TIM_CHANNEL_3, 50, false, false);
			//HAL_Delay(1000);
			BSP_TIMER_enable_PWM(TIMER2_ID, TIM_CHANNEL_1, 25, false, true);
			HAL_Delay(1000);
			BSP_TIMER_enable_PWM(TIMER2_ID, TIM_CHANNEL_2, 25, false, false);
			HAL_Delay(1000);


		}

		BSP_TIMER_enable_PWM(TIMER3_ID, TIM_CHANNEL_3, 50, false, false);
		//BSP_TIMER_enable_PWM(TIMER3_ID, TIM_CHANNEL_4, 150, false, false);
		BSP_TIMER_enable_PWM(TIMER1_ID, TIM_CHANNEL_3, 50, false, false);
		BSP_TIMER_enable_PWM(TIMER2_ID, TIM_CHANNEL_1, 50, false, false);
		BSP_TIMER_enable_PWM(TIMER2_ID, TIM_CHANNEL_2, 50, false, false);

		//rapport cyclique reglé pour une position servo de 50%
		SERVO_set_position(TIMER3_ID, TIM_CHANNEL_1,100);
		SERVO_set_position(TIMER3_ID, TIM_CHANNEL_3,0);
		SERVO_set_position(TIMER2_ID, TIM_CHANNEL_1,50);
		SERVO_set_position(TIMER1_ID, TIM_CHANNEL_3,0);
		SERVO_set_position(TIMER2_ID, TIM_CHANNEL_2,0);
	 }




//position est exprimée de 0 à 100.
void SERVO_set_position(timer_id_t timer_id,uint16_t TIM_CHANNEL_x,uint16_t position){

		if(position > 100)
			position = 100; //écretage si l'utilisateur demande plus de 100%
		current_position = position;
		// Conversion de la position en rapport cyclique (‰)
		uint16_t duty_per_mille = position + 100;  // de 100 à 200 pour 0% à 100%

		// Appel de la fonction timer avec conversion interne en ticks
		BSP_TIMER_set_duty(timer_id, TIM_CHANNEL_x, duty_per_mille);

	}
/*void SERVO_set_angle(timer_id_t timer, uint32_t channel, uint16_t angle) {
    if (angle > 180) angle = 180;
    // Calcul du Pulse (0.5ms à 2.5ms pour 0-180°)
    // Dépend de ta configuration ARR et PSC du Timer
    uint32_t pulse = 500 + (angle * 2000 / 180);
    __HAL_TIM_SET_COMPARE(get_timer_handle(timer), channel, pulse);
}*/
void SERVO_set_angle(timer_id_t timer, uint32_t channel, uint16_t angle) {
    if (angle > 180) angle = 180;

    // Calcul du Pulse (0.5ms à 2.5ms soit environ 5% à 12.5% du rapport cyclique)
    // Attention : ces valeurs dépendent de votre ARR (Auto-Reload Register).
    // Si ARR = 20000, alors 0° = 1000 et 180° = 2500.
    uint32_t pulse = 20000 + (angle * 1000 / 180);

    if (timer == TIMER2_ID) {
        __HAL_TIM_SET_COMPARE(&htim2, channel, pulse);
    }
    else if (timer == TIMER3_ID) {
        __HAL_TIM_SET_COMPARE(&htim3, channel, pulse);
    }
    else if (timer == TIMER1_ID) {
        __HAL_TIM_SET_COMPARE(&htim1, channel, pulse);
    }
}

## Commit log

2026-09-19 Ce dépôt contient le développement complet d’un bras robotique autonome basé sur un microcontrôleur STM32G431 et la DEEP Purple Complete Board. Le système est conçu pour détecter, saisir, trier et dé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
    Ce dépôt contient le développement complet d’un bras robotique autonome basé sur un microcontrôleur STM32G431 et la DEEP Purple Complete Board.
    Le système est conçu pour détecter, saisir, trier et déplacer des objets grâce à une combinaison de capteurs, de servomoteurs et d’algorithmes embarqués.
    [projet_pcb_nucleo_g431.PCBDOC, projet_pcb_nucleo_g431.PrjPCB, projet_pcb_nucleo_g431.SchDoc]
2026-09-22 projet de bras robotique assister trie
    projet de bras robotique assister trie
